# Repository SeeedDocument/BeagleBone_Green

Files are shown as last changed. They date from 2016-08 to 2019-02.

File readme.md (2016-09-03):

BeagleBone Green
---

**SKU**: [102010027](http://www.seeedstudio.com/SeeedStudio-BeagleBone-Green-p-2504.html)

**Wiki Link**: [wiki.seeed.cc](wiki.seeed.cc)

###Change Log:

- **2016-8-29:** update and create repos by loovee (loovee@seeed.cc)

--------
This document is written by Seeed Studio and is licensed under MIT License.

Contributing to this document is warmly welcomed. You can do this basically by
[forking](https://help.github.com/articles/fork-a-repo), committing modifications and then [pulling requests](https://help.github.com/articles/using-pull-requests) (follow the links above
for operating guide). Adding change log and your contact into file header is encouraged.
Thanks for your contribution.

Seeed is a hardware innovation platform for makers to grow inspirations into differentiating products. By working closely with technology providers of all scale, Seeed provides accessible technologies with quality, speed and supply chain knowledge. When prototypes are ready to iterate, Seeed helps productize 1 to 1,000 pcs using in-house engineering, supply chain management and agile manufacture forces. Seeed also team up with incubators, Chinese tech ecosystem, investors and distribution channels to portal Maker startups beyond.

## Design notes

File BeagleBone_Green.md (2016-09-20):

---
title: BeagleBone Green
category: BeagleBone, IoT
bzurl: https://www.seeedstudio.com/SeeedStudio-BeagleBone-Green-p-2504.html
oldwikiname: BeagleBone_Green
prodimagename: cover.jpg
surveyurl: https://www.research.net/r/seeed_bbg
sku: 102010027
---

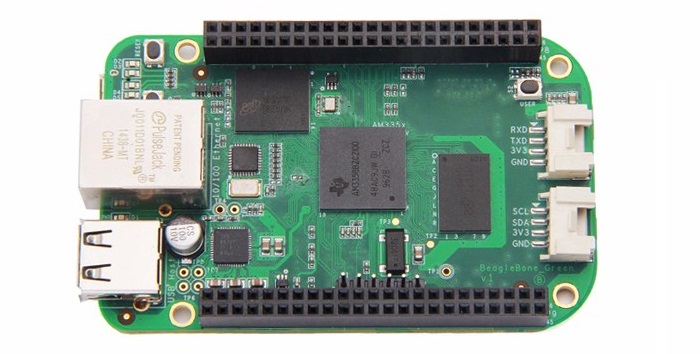
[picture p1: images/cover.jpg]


SeeedStudio BeagleBone Green (BBG) is a low cost, open-source, community supported development platform for developers and hobbyists. It is a joint effort by [BeagleBoard.org](http://beagleboard.org/) and Seeed Studio. It is based on the classical open-source hardware design of [BeagleBone Black](http://beagleboard.org/black) and developed into this differentiated version. The BBG includes two Grove connectors, making it easier to connect to the large family of Grove sensors. The on-board HDMI is removed to make room for these Grove connectors.

Boot Linux in under 10 seconds and get started on development in less than 5 minutes with just a single USB cable.

(http://www.seeedstudio.com/SeeedStudio-BeagleBone-Green-p-2504.html)

##Features
------

* **Fully Compatible with BeagleBone Black**
* **Processor: AM335x 1GHz ARMR Cortex-A8**
    * 512MB DDR3 RAM
    * 4GB 8-bit eMMC on-board flash storage
    * 3D graphics accelerator
    * NEON floating-point accelerator
    * 2x PRU 32-bit microcontrollers
* **Connectivity**
    * USB client for power & communications
    * USB host
    * Ethernet
    * 2x 46 pin headers
    * 2x Grove connectors (I2C and UART)
* **Software Compatibility**
    * Debian
    * Android
    * Ubuntu
    * Cloud9 IDE on Node.js w/ BoneScript library
    * plus much more

##Specification
------

|Item|Value|
|----|---|
|Processor|	AM335x 1GHz ARMR Cortex-A8|
|RAM|	512MB DDR3|
|on-board Flash Storage	|4GB eMMC|
|CPU Supports	|NEON floating-point & 3D graphics accelerator|
|Micro USB	Supports |powering & communications|
|USB |Host	1|
|Grove Connectors	|2 (One I2C and One UART) |
|GPIO	|2 x 46 pin headers|
|Ethernet	|1|
|Operating Temperature	|0 ~ 75 |

##Application Ideas

* Internet of Things
* Smart House
* Industrial
* Automation & Process Control
* Human Machine Interface
* Sensor Hub
* Robot

Here are some funny projects for your reference.

|Home Center|Retro Lamp|Drive a Motor|
|---|-----|---|
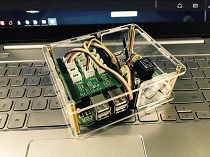
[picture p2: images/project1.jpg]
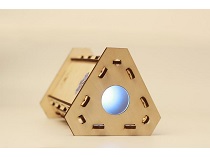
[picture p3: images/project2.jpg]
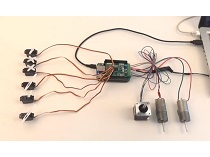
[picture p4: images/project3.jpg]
||||
|[MAKE IT NOW!](http://www.instructables.com/id/Home-Control-Center-Using-BeagleBone-Green-Wireles/)|[MAKE IT NOW!](http://www.instructables.com/id/DIY-a-Retro-Wooden-Lamp-with-BBG/)|[MAKE IT NOW!](http://www.instructables.com/id/A-BeagleBone-Tutorial-Getting-Started-With-Motor-B/)|

|BBG Acrylic Case|GPIO Control|Smart Light|
|---|-----|---|
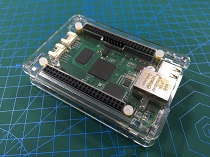
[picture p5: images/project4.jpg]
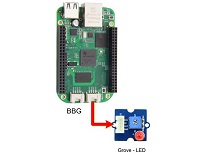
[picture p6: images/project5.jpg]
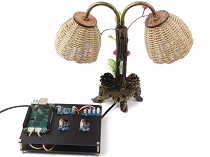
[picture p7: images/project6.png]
||||
|[MAKE IT NOW!](http://www.instructables.com/id/5-Design-of-Laser-Cut-Cases-for-5-Popular-Platform/)|[MAKE IT NOW!](http://www.seeed.cc/How-to-use-the-Grove-UART-port-as-a-GPIO-on-BBG-p-365.html)|[MAKE IT NOW!](http://www.seeed.cc/Smart-Light-Demo-with-BBG-%26amp%3B-BBG-Start-Kit(HA)-p-366.html)|

##Hardware Overview

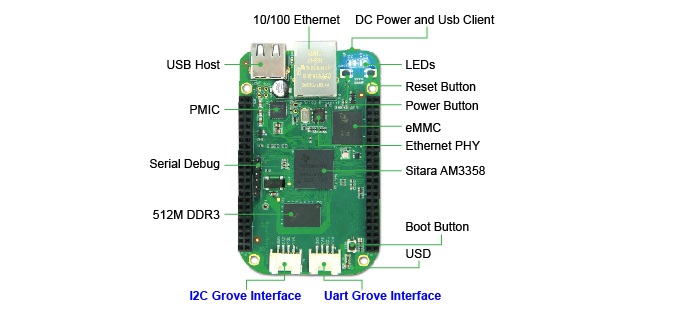
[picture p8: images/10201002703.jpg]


* **USB Host** - USB Host
* **DC Power and USB Client** - Power the board and act as client
* **LEDs**
    * **D2** is configured at boot to blink in a heartbeat pattern
    * **D3** is configured at boot to light during microSD card accesses
    * **D4** is configured at boot to light during CPU activity
    * **D5** is configured at boot to light during eMMC accesses
* **Boot button**
    * When there's a SD card insert, the system will boot from SD card first, if you want to boot from eMMC, press this button and then power on. 
    * Use as a normal button after boot, connect to **GPIO_72**
* **I2C Grove Interface** - Connected to **I2C2**
* **Uart Grove Interface** - Connected to **UART2**
* **Serial Debug** - Connect to **UART0**, PIN1~PIN6: GND, NC, NC, RX, TX, NC, note that pin1 is near to the USB.

###Pin map

Each digital I/O pin has 8 different modes that can be selected, including GPIO.

####65 Possible Digital I/Os

!!!Note
    In GPIO mode, each digital I/O can produce interrupts.

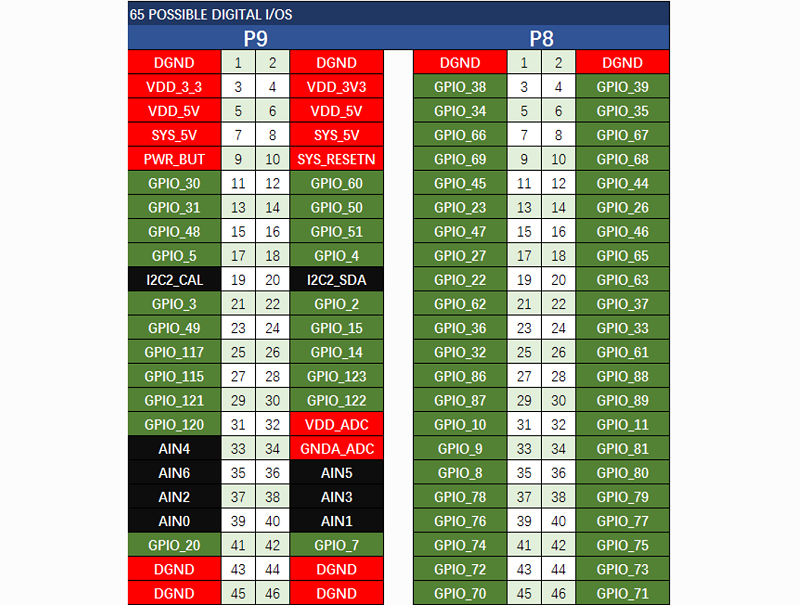
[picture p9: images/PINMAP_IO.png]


####PWMs and Timers

!!!Note
    Up to 8 digital I/O pins can be configured with pulse-width modulators (PWM) to produce signals to control motors or create pseudo analog voltage levels, without taking up any extra CPU cycles.

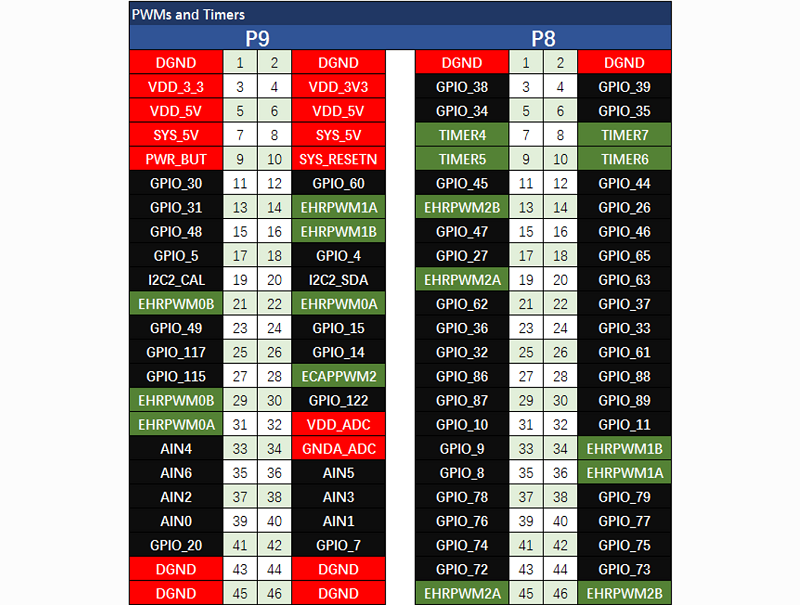
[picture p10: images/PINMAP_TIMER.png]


####Analog Inputs

!!!Note
    Make sure you don't input more than 1.8V to the analog input pins. This is a single 12-bit analog-to-digital converter with 8 channels, 7 of which are made available on the headers.

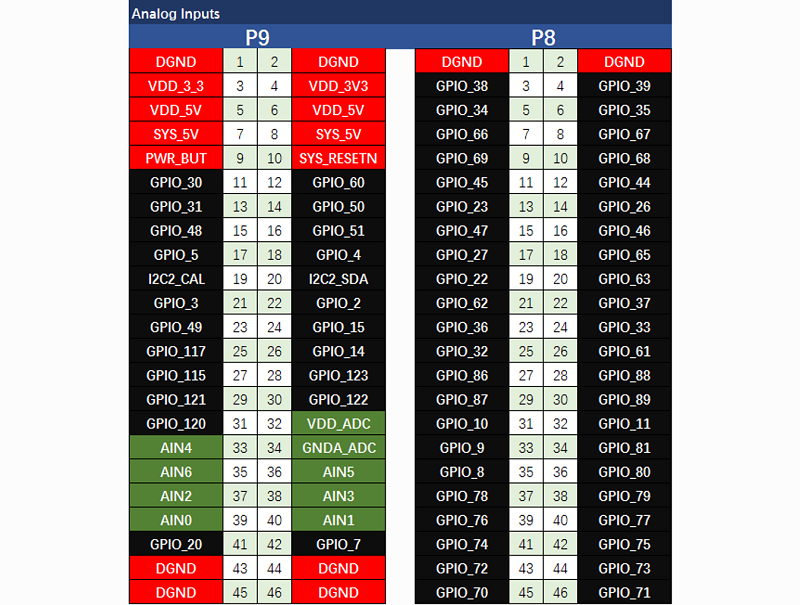
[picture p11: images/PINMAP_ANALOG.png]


####UART

!!!Note
    There is a dedicated header for getting to the UART0 pins and connecting a debug cable. Five additional serial ports are brought to the expansion headers, but one of them only has a single direction brought to the headers.

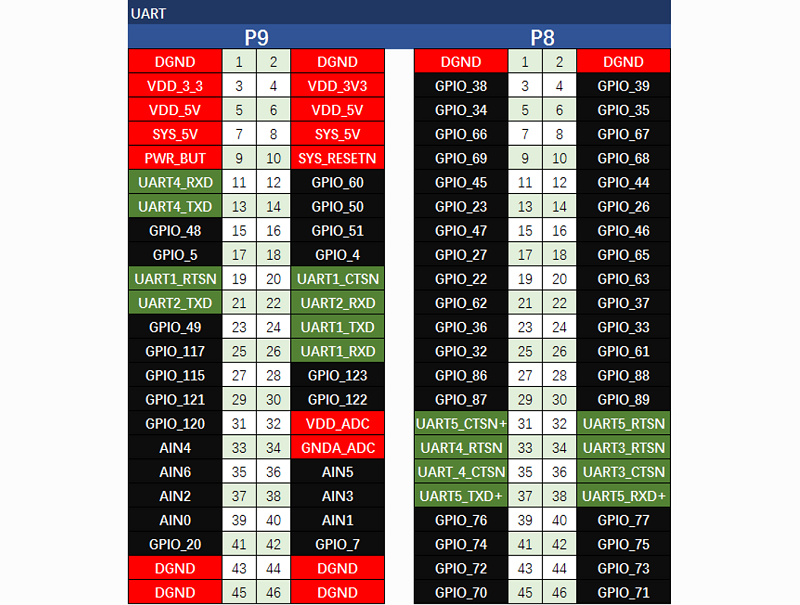
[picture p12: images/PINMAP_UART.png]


####I2C

!!!Note
    The first I2C bus is utilized for reading EEPROMS on cape add-on boards and can't be used for other digital I/O operations without interfering with that function, but you can still use it to add other I2C devices at available addresses. The second I2C bus is available for you to configure and use.

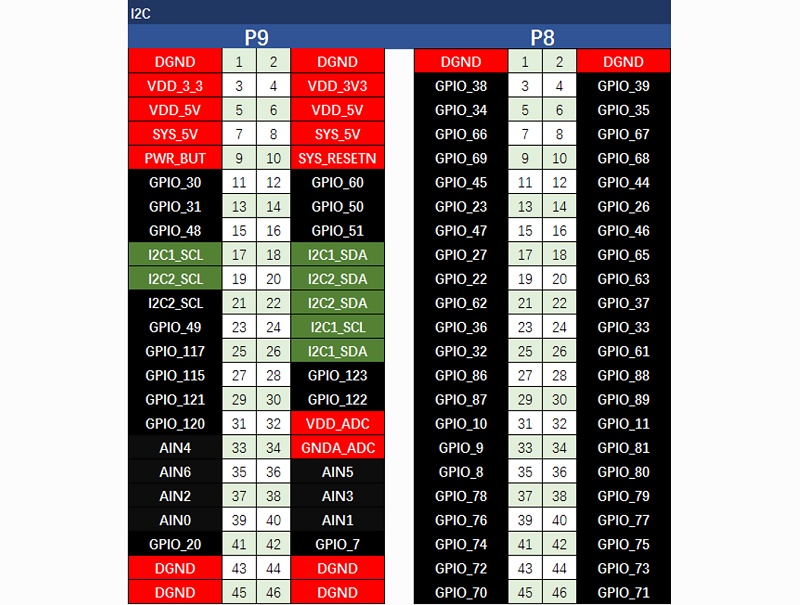
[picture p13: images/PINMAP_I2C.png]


####SPI

!!!Note
    For shifting out data fast, you might consider using one of the SPI ports.

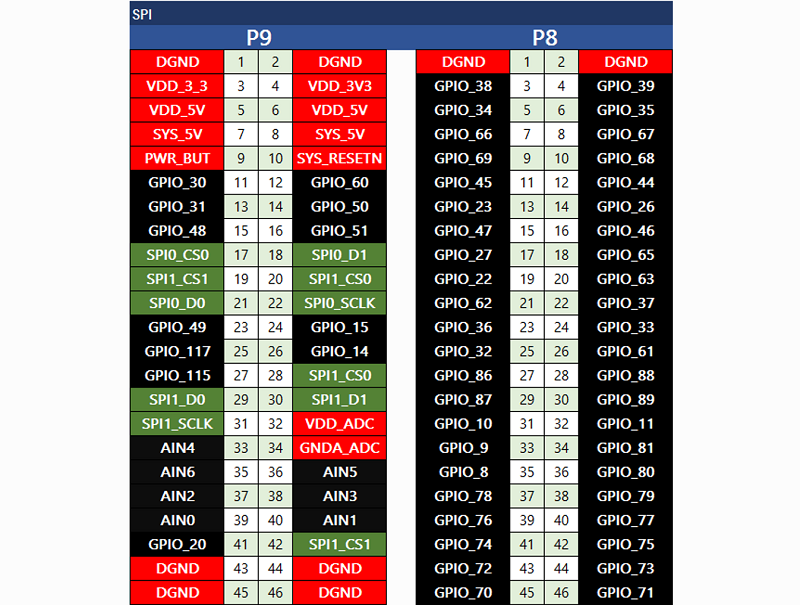
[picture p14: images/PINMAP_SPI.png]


##Getting Started
------

!!!Note
    This chapter is writing under Win10. The steps are familiar for the other operate systems.

###STEP1. Plug in your BBG via USB

Use the provided micro USB cable to plug your BBG into your computer. This will both power the board and provide a development interface. BBG will boot Linux from the on-board 2GB or 4GB eMMC. 

BBG will operate as a flash drive providing you with a local copy of the documentation and drivers. Note that this interface may not be used to re-configure the microSD card with a new image, but may be used to update the boot parameters using the uEnv.txt file.

You'll see the PWR LED lit steadily. Within 10 seconds, you should see the other LEDs blinking in their default configurations.

* D2 is configured at boot to blink in a heartbeat pattern
* D3 is configured at boot to light during microSD card accesses
* D4 is configured at boot to light during CPU activity
* D5 is configured at boot to light during eMMC accesses

###STEP2. Install Drivers

Install the drivers for your operating system to give you network-over-USB access to your Beagle. Additional drivers give you serial access to your board.

|Operating System |	USB Drivers |	Comments |
|---|---|---|
|Windows (64-bit) |	[64-bit installer](http://beagleboard.org/static/Drivers/Windows/BONE_D64.exe)	 | |
|Windows (32-bit) |	[32-bit installer](http://beagleboard.org/static/Drivers/Windows/BONE_DRV.exe)||
|Mac OS X|[Network](http://beagleboard.org/static/Drivers/MacOSX/RNDIS/HoRNDIS.pkg) [Serial](http://beagleboard.org/static/Drivers/MacOSX/FTDI/EnergiaFTDIDrivers2.2.18.pkg) | Install both sets of drivers.|
|Linux|[mkudevrule.sh](http://beagleboard.org/static/Drivers/Linux/FTDI/mkudevrule.sh)|Driver installation isn't required, but you might find a few udev rules helpful.|

!!!Note
    For window system, please note that:
    
    * Windows Driver Certification warning may pop up two or three times. Click "Ignore", "Install" or "Run"
    * To check if you're running 32 or 64-bit Windows see [this](https://support.microsoft.com/kb/827218).
    *  On systems without the latest service release, you may get an error (0xc000007b). In that case, please [install](https://www.microsoft.com/en-us/download/confirmation.aspx?id=13523) and retry: 
    * You may need to reboot Windows.
    * These drivers have been tested to work up to Windows 10

!!!Note
    Additional FTDI USB to serial/JTAG information and drivers are available from [https://www.ftdichip.com/Drivers/VCP.htm](https://www.ftdichip.com/Drivers/VCP.htm).

!!!Note
    Additional USB to virtual Ethernet information and drivers are available from [https://www.linux-usb.org/gadget/](https://www.linux-usb.org/gadget/) and [https://joshuawise.com/horndis](https://joshuawise.com/horndis).

###STEP3. Browse to your Beagle

Using either Chrome or Firefox (Internet Explorer will NOT work), browse to the web server running on your board. It will load a presentation showing you the capabilities of the board. Use the arrow keys on your keyboard to navigate the presentation.

Click [http://192.168.7.2](http://192.168.7.2) to launch to your BBG.
Older software images require you to EJECT the BEAGLE_BONE drive to start the network. With the latest software image, that step is no longer required.

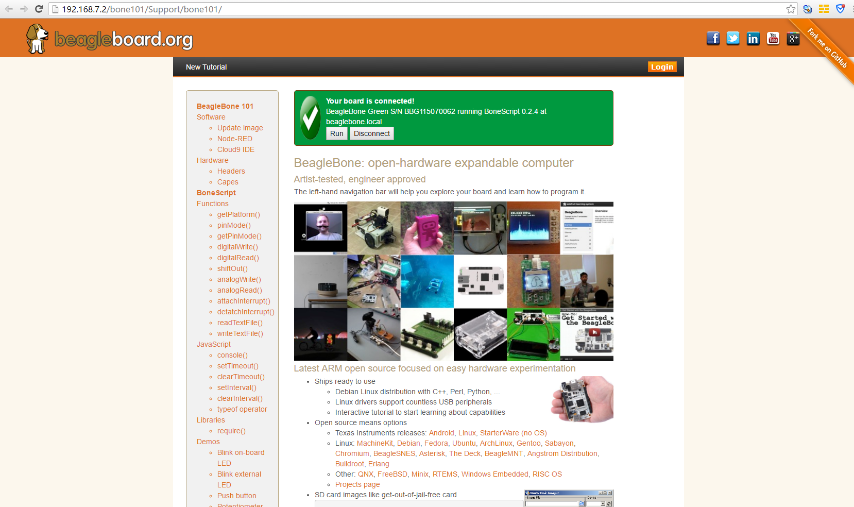
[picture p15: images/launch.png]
Click to view larger image


###STEP4. Cloud9 IDE

To begin editing programs that live on your board, you can use the Cloud9 IDE by click

(http://192.168.7.2:3000/ide.html)

##Update to latest software
-----

You need to update the board to latest software to keep a better performance, here we will show you how to make it step by step. 

###STEP1. Download the latest software image

First of all, you have to download the suitable image here. 

(http://beagleboard.org/latest-images)

!!!Note
    Due to sizing necessities, this download may take about 30 minutes or more. 

The file you download will have an **.img.xz** extension. This is a compressed sector-by-sector image of the SD card. 

###STEP2. Install compression utility and decompress the image

Download and install [7-zip.](http://www.7-zip.org/download.html) 

!!!Note
    Choose a version that suitable for your system.

Use 7-zip to decompress the SD card **.img file**

###STEP3. Install SD card programming utility

Download and install [Image Writer for Windows](https://sourceforge.net/projects/win32diskimager/files/latest/download). Be sure to download the binary distribution.

###STEP4. Write the image to your SD card

You need a SD adapter to connect your microSD card to your computer at the first. Then use the software Image Write for Windows to write the decompressed image to your SD card.

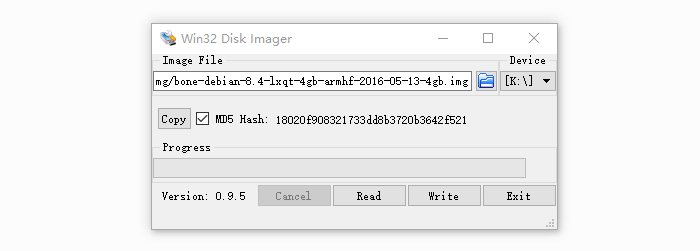
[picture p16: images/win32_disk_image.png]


Click on **Write** button, then the process is started. 

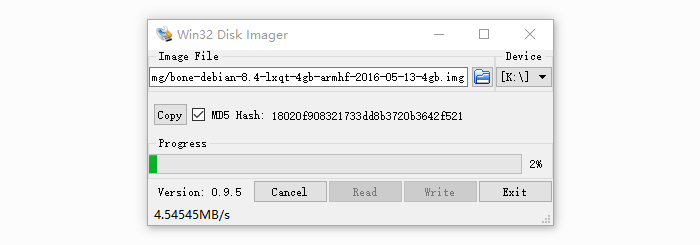
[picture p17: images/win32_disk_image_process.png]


!!!Note
    * You may see a warning about damaging your device. This is fine to accept as long as you are pointing to your SD card for writing.
    * You should not have your BeagleBone connected to your computer at this time.
    * This process may need up to 10 minutes.

###STEP5. Boot your board off of the SD card

Insert SD card into your (powered-down first) board. Then the board will boot from the SD card.

!!!Note
    If you don't need to write the image to your on-board eMMC, you don't need to read the last of this chapter.  Otherwise pleas go ahead.

If you desire to write the image to your on-board eMMC, you need to launch to the board, and modify a file. 

In **/boot/uEnv.txt**:

    ##enable BBB: eMMC Flasher:
    #cmdline=init=/opt/scripts/tools/eMMC/init-eMMC-flasher-v3.sh
Change to:

    ##enable BBB: eMMC Flasher:
    cmdline=init=/opt/scripts/tools/eMMC/init-eMMC-flasher-v3.sh

Then you will find the 4 user led light as below

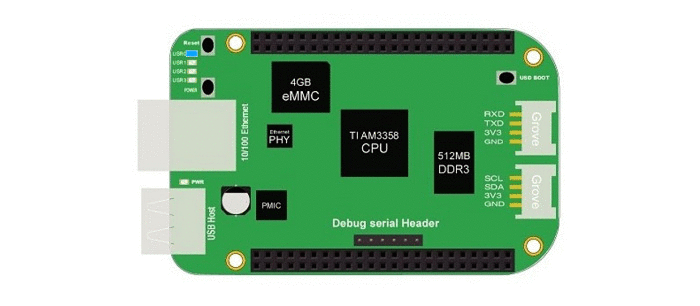
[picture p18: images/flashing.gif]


!!!Note
    If you don't find the upper tracing light, please press the RESET button to reset the board. 
    
When the flashing is complete, all 4 USRx LEDs will be **off**. The latest Debian flasher images automatically power down the board upon completion. This can take up to **10 minutes**. Power-down your board, remove the SD card and apply power again to be complete.

##Grove for BBG
------

Grove is a modular, standardized connecter prototyping system. Grove takes a building block approach to assembling electronics. Compared to the jumper or solder based system, it is easier to connect, experiment and build and simplifies the learning system, but not to the point where it becomes dumbed down.  Some of the other prototype systems out there takes the level down to building blocks.   Good stuff to be learned that way, but the Grove system allows you to build real systems.   It requires some learning and expertise to hook things up.

Below listed the Grove modules that work well with BBG.

|SKU |Name|Interface|link|
|---|-----|-----|---|
|101020054  |Grove - 3-Axis Digital Accelerometer(+16g) |	I2C| [link](http://www.seeedstudio.com/Grove-3-Axis-Digital-Accelerometer%28%C2%B116g%29-p-1156.html)|
|101020071  |Grove - 3-Axis Digital Accelerometer(+400g) |	I2C| [link](http://www.seeedstudio.com/Grove-3-Axis-Digital-Accelerometer%28%C2%B1400g%29-p-1897.html)|
|101020034  |Grove - 3-Axis Digital Compass |	I2C| [link](http://www.seeedstudio.com/Grove-3-Axis-Digital-Compass-p-759.html)|
|101020050  |Grove - 3-Axis Digital Gyro |	Analog| [link](http://www.seeedstudio.com/Grove-3-Axis-Digital-Gyro-p-750.html)|
|101020081	|Grove - 6-Axis Accelerometer&Compass v2.0 |	I2C| [link](http://www.seeedstudio.com/Grove-6-Axis-Accelerometer&Compass-v2.0-p-2476.html)|
|101020072	|Grove - Barometer Sensor(BMP180) |	I2C| [link](http://www.seeedstudio.com/Grove-Barometer-Sensor-%28BMP180%29-p-1840.html)|
|104030010	|Grove - Blue LED |	I/O| [link](http://www.seeedstudio.com/Grove-Blue-LED-p-1139.html)|
|101020003	|Grove - Button	 |I/O| [link](http://www.seeedstudio.com/Grove-Button-p-766.html)|
|111020000	|Grove - Button(P)	 |I/O| [link](http://www.seeedstudio.com/Grove-Button%28P%29-p-1243.html)|
|107020000	|Grove - Buzzer	 |I/O| [link](http://www.seeedstudio.com/Grove-Buzzer-p-768.html)|
|104030006	|Grove - Chainable RGB LED	 |I2C| [link](http://www.seeedstudio.com/Grove-Chainable-RGB-LED-p-850.html)|
|101020030	|Grove - Digital Light Sensor	 |I2C| [link](http://www.seeedstudio.com/Grove-Digital-Light-Sensor-p-1281.html)|
|103020024	|Grove - Finger-clip Heart Rate Sensor	 |I2C| [link](http://www.seeedstudio.com/Grove-Finger-clip-Heart-Rate-Sensor-p-2425.html)|
|101020082	|Grove - Finger-clip Heart Rate Sensor with shell	|I2C|[link](http://www.seeedstudio.com/Grove-Finger-clip-Heart-Rate-Sensor-with-shell-p-2420.html)|
|113020003	|Grove - GPS	 |UART| [link](http://www.seeedstudio.com/Grove-GPS-p-959.html)|
|104030007	|Grove - Green LED	|I/O| [link](http://www.seeedstudio.com/Grove-Green-LED-p-1144.html)|
|103020013	|Grove - I2C ADC	|I2C| [link](http://www.seeedstudio.com/Grove-Green-LED-p-1144.html)|
|103020006	|Grove - I2C Hub	|I2C| [link](http://www.seeedstudio.com/Grove-I2C-Hub-p-851.html)|
|101020079	|Grove - IMU 10DOF	|I2C| [link](http://www.seeedstudio.com/Grove-IMU-10DOF-p-2386.html)|
|101020080	|Grove - IMU 9DOF v2.0	|I2C| [link](http://www.seeedstudio.com/Grove-IMU-9DOF-v2.0-p-2400.html)|
|101020040	|Grove - IR Distance Interrupter	|I/O| [link](http://www.seeedstudio.com/Grove-IR-Distance-Interrupter-p-1278.html)|
|104030011	|Grove - OLED Display 0.96''	|I2C| [link](http://www.seeedstudio.com/Grove-OLED-Display-1.12%22-p-824.html)|
|104030008	|Grove - OLED Display 1.12''	|I2C| [link](http://www.seeedstudio.com/Grove-OLED-Display-0.96%22-p-781.html)|
|104030005	|Grove - Red LED	|I/O| [link](http://www.seeedstudio.com/Grove-Red-LED-p-1142.html)|
|103020005	|Grove - Relay	|I/O| [link](http://www.seeedstudio.com/Grove-Relay-p-769.html)|
|316010005	|Grove - Servo	|I/O| [link](http://www.seeedstudio.com/Grove-Servo-p-1241.html)|
|101020023	|Grove - Sound Sensor	|Analog| [link](http://www.seeedstudio.com/Grove-Sound-Sensor-p-752.html)|
|101020004	|Grove - Switch(P)	|I/O| [link](http://www.seeedstudio.com/Grove-Switch%28P%29-p-1252.html)|
|101020015	|Grove - Temperature Sensor	|Analog| [link](http://www.seeedstudio.com/Grove-Temperature-Sensor-p-774.html)|
|101020019	|Grove - Temperature&Humidity Sensor Pro	|Analog| [link](http://www.seeedstudio.com/Grove-Temperature&Humidity-Sensor-Pro-p-838.html)|

##Cape for BBG
-------

You will need some expansion board when you start a project. There're many cape for BBG already, they include LCD display, motor driver as well as HDMI expansion etc. Below is some of them recommend.

|Grove Cape| Motor Bridge Cape|HDMI Cape|
|---|---|---|
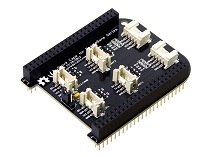
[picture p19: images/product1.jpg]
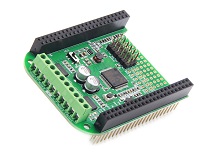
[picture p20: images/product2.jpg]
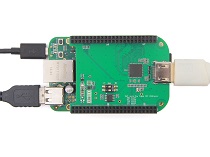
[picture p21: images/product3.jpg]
||||
|[GET ONE NOW!](http://www.seeedstudio.com/Grove-Cape-for-BeagleBone-Series-p-1718.html)|[GET ONE NOW!](http://www.seeedstudio.com/Motor-Bridge-Cape-p-2569.html)|[GET ONE NOW!](http://www.seeedstudio.com/SeeedStudio-BeagleBone-Green-HDMI-Cape-p-2570.html)|

|Grove Cape| 5 Inch LCD|7 Inch LCD|
|---|---|---|
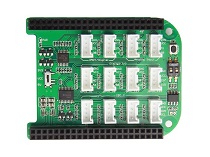
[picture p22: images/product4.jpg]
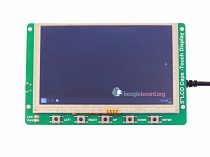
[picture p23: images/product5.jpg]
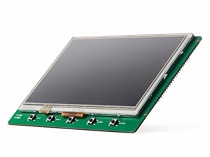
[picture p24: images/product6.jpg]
||||
|[GET ONE NOW!](http://www.seeedstudio.com/Grove-Base-Cape-for-Beaglebone-v2.0-p-2644.html)|[GET ONE NOW!](http://www.seeedstudio.com/5-Inch-BeagleBone-Green-LCD-Cape-with-Resistive-Touch-p-2642.html)|[GET ONE NOW!](http://www.seeedstudio.com/7-Inch-BeagleBone-Green-LCD-Cape-with-Resistive-Touch-p-2643.html)|

##References and Resources

###References
There're many references to help you to get more information about the board. 

* [BeagleBoard Main Page](http://beagleboard.org/)
* [BeagleBone Green info at BeagleBoard page](http://beagleboard.org/green)
* [BeagleBoard Getting Started](http://beagleboard.org/getting-started)
* [Troubleshooting](http://beagleboard.org/getting-started#troubleshooting)
* [Hardware documentation](http://beagleboard.org/getting-started#hardware)
* [Projects of BeagleBoard](http://beagleboard.org/project)

###Resources
-----

* [BEAGLEBONE_GREEN SRM(v1a)(pdf)](https://github.com/SeeedDocument/BeagleBone_Green/raw/master/resources/BBG_SRM_V1a_20151009.pdf)
* [BEAGLEBONE_GREEN Schematic(pdf)](https://github.com/SeeedDocument/BeagleBone_Green/raw/master/resources/BEAGLEBONE_GREEN_V1.pdf)
* [BEAGLEBONE_GREEN Schematic(OrCAD)](https://github.com/SeeedDocument/BeagleBone_Green/raw/master/resources/BEAGLEBONE_GREEN_V1_166%28sch%29.rar)
* [BEAGLEBONE_GREEN PCB(OrCAD)](https://github.com/SeeedDocument/BeagleBone_Green/blob/master/resources/BeagleBone_Green_v1.166%28board%29.rar)

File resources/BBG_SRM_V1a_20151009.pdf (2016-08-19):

REF: BBONEGRN_SRM | BeagleBone Green
System Reference Manual | Rev V1a


# BeagleBone Green System Reference Manual

Revision v1
Oct 9, 2015
Reference to the BBB_SRM

System Reference Manual | Rev V1a

THIS DOCUMENT

This work is licensed under the Creative Commons Attribution-Share Alike 3.0 Unported License. To view a copy of this license, visit http://creativecommons.org/licenses/by-sa/3.0/ or send a letter to Creative Commons, 171 Second Street, Suite 300, San Francisco, California, 94105, USA.

All derivative works are to be attributed to Gerald Coley of BeagleBoard.org.

For more information, see http://creativecommons.org/license/results-one?license_code=by-sa

This document is derived from work by Gerald Coley (gerald@beagleboard.org), for hardware questions, please send your email to XiangNan Qu (xiangnan.qu@seeed.cc), for software and ecosystem questions, please direct to Jason Kridner (jkridner@beagleboard.org) and http://beagleboard.org/discuss.

Send all comments and errors concerning this document to the author at xiangnan.qu@seeed.cc

All information in this document is subject to change without notice.

For an up to date version of this document refer to:

http://www.seeedstudio.com/wiki/beaglebone_green

System Reference Manual | Rev V1a

BEAGLEBONE DESIGN

These design materials referred to in this document are *NOT SUPPORTED* and DO NOT constitute a reference design. Only “community” support is allowed via resources at BeagleBoard.org/discuss.

THERE IS NO WARRANTY FOR THE DESIGN MATERIALS, TO THE EXTENT PERMITTED BY APPLICABLE LAW. EXCEPT WHEN OTHERWISE STATED IN WRITING THE COPYRIGHT HOLDERS AND/OR OTHER PARTIES PROVIDE THE DESIGN MATERIALS “AS IS” WITHOUT WARRANTY OF ANY KIND, EITHER EXPRESSED OR IMPLIED, INCLUDING, BUT NOT LIMITED TO, THE IMPLIED WARRANTIES OF MERCHANTABILITY AND FITNESS FOR A PARTICULAR PURPOSE. THE ENTIRE RISK AS TO THE QUALITY AND PERFORMANCE OF THE DESIGN MATERIALS IS WITH YOU. SHOULD THE DESIGN MATERIALS PROVE DEFECTIVE, YOU ASSUME THE COST OF ALL NECESSARY SERVICING, REPAIR OR CORRECTION.

This board was designed as an evaluation and development tool. It was not designed with any other application in mind. As such, the design materials that are provided which include schematic, BOM, and PCB files, may or may not be suitable for any other purposes. If used, the design material becomes your responsibility as to whether or not it meets your specific needs or your specific applications and may require changes to meet your requirements.

System Reference Manual | Rev V1a

## Table of Contents

### 1.0 Introduction6 2.0 Change History 6

### 3.0 Connecting Up Your BeagleBone Green 7

### 4.0 BeagleBone Green Overview 11

5.0 | BeagleBone Green High Level Specification | 15

System Reference Manual | Rev V1a

### 6.0 BeagleBone Green Mechanical 22

### 7.0 Pictures 24 8.0 Support Information 26

## Tables

Table 1.Change History 6
Table 2.BeagleBone Green Features 12

## Figures

Figure 1. | In The Box 7
Figure 2. | Tethered Configuration 8
Figure 3. | USB Connection to the Board 9
Figure 4. | Board Power LED | 10
Figure 5. | Board Boot Status | 10
Figure 6. | Connectors, LEDs and Switches | 13
Figure 7. | Key Components14
Figure 8. | BeagleBone Green Block diagram15
Figure 9. | Board Dimensions | 23
Figure 10. Top Side24
Figure 11. Bottom Side 25

System Reference Manual | Rev V1a

## 1.0 Introduction

This document is the System Reference Manual for the BeagleBone Green and covers its use and design. The board will primarily be referred to in the remainder of this document simply as the board, although it may also be referred to as the BeagleBone Green as a reminder. There are also references to the original BeagleBone as well, and will be referenced as simply BeagleBone.

This design is subject to change without notice as we will work to keep improving the design as the product matures based on feedback and experience. Software updates will be frequent and will be independent of the hardware revisions and as such not result in a change in the revision number.

Make sure you check the support Wiki frequently for the most up to date information. http://www.seeedstudio.com/wiki/beaglebone_green

## 2.0 Change History

This section describes the change history of this document and board. Document changes are not always a result of a board change. A board change will always result in a document change.

### 2.1 Document Change History

Table 1. Change History
REV | Description | Date | By
V1 | Production release | June 3, 2015 | QXN
V1a | Fixed the Features and Specification Table | Oct 9, 2015 | QXN

System Reference Manual | Rev V1a

## 3.0 Connecting Up Your BeagleBone Green

This section provides instructions on how to hook up your board. Two scenarios will be discussed:

1) Tethered to a PC and
2) As a standalone development platform in a desktop PC configuration.

### 3.1 What’s In the Box

In the box you will find three main items as shown in Figure 1.

- BeagleBone Green
- Micro USB to USB Type A Cable
- Instruction card with link to the support WIKI address.

This is sufficient for the tethered scenario and creates an out of box experience where the board can be used immediately with no other equipment needed.


Figure 1. In The Box

System Reference Manual | Rev V1a

### 3.2 Main Connection Scenarios

This section will describe how to connect the board for use. This section is basically a slightly more detailed description of the Quick Start Guide that came in the box. There is also a Quick Start Guide document on the board that should also be referred to. The intent here is that someone looking t purchase the board will be able to read this section and get a good idea as to what the initial set up will be like.

The board can be configured in several different ways, but we will discuss the most common scenarios as described in the Quick Start Guide card that comes in the box.

### 3.3 Tethered To A PC

In this configuration, the board is powered by the PC via the provided USB cable--no other cables are required. The board is accessed either as a USB storage drive or via the browser on the PC. You need to use either Firefox or Chrome on the PC, IEx will not work properly. Figure 2 shows this configuration.


Figure 2. Tethered Configuration

System Reference Manual | Rev V1a

All the power for the board is provided by the PC via the USB cable. In some instances, the PC may not be able to supply sufficient power for the board. In that case, an external 5VDC power supply can be used to power the board through VDD_5V pin in P9 connector, but this should rarely be necessary.

### 3.3.1 Connect the Cable to the Board

1. Connect the small connector on the USB cable to the board as shown in Figure 4. The connector is on the bottom side of the board.


Figure 3. USB Connection to the Board

2. Connect the large connector of the USB cable to your PC or laptop USB port.
3. The board will power on and the power LED will be on as shown in Figure 4 below.


System Reference Manual | Rev V1a

Figure 4. Board Power LED

4. When the board starts to the booting process started by the process of applying power, the LEDs will come on in sequence as shown in Figure 5 below. It will take a few seconds for the status LEDs to come on, so be patient. The LEDs will be flashing in an erratic manner as it begins to boot the Linux kernel.

Figure 5. Board Boot Status

System Reference Manual | Rev V1a

### 3.3.2 Accessing the Board as a Storage Drive

The board will appear around a USB Storage drive on your PC after the kernel has booted, which will take a round 10 seconds. The kernel on the board needs to boot before the port gets enumerated. Once the board appears as a storage drive, do the following:

1) Open the USB Drive folder.
2) Click on the file named start.html
3) The file will be opened by your browser on the PC and you should get a display showing the Quick Start Guide.
4) Your board is now operational! Follow the instructions on your PC screen.

## 4.0 BeagleBone Green Overview

BeagleBone Green (BBG) is based on the classical open-source hardware design of BeagleBone Black (BBB) and added two Grove connectors. It has removed the HDMI port on the BBB and also updated the 5V barrel to Micro USB host.

The main improvement about BeagleBone Green is that adding two Grove connector for supporting Grove system. For more information about Grove system please visit: http://www.seeedstudio.com/wiki/Grove_System

### 4.1 BeagleBone Black Compatibility

The board is intended to be compatible with the BeagleBone Black as much as possible. There are several areas where there are differences between the two designs. These differences are listed below, along with the reasons for the differences.

- Removed the 5VDC Power Jack
- Cost down
- Rarely used
- Normally you can power the board through the Micro USB port
- Removed HDMI framer IC and connector
- Cost down
- If you still need to display with HDMI interface, you can add a HDMI cape
- Replace Mini USB port with Micro USB
- More commonly used
- Grove interface onboard
- There are more than 100 Grove Sensors and Actuators can be easily used
- Focus on the IoT applications

System Reference Manual | Rev V1a

### 4.2 BeagleBone Green Features and Specification

Table 2. BeagleBone Green Features
| Feature
Processor | Sitara AM3358BZCZ100 1GHz, 2000 MIPS
Graphics Engine | SGX530 3D, 20M Polygons/S
SDRAM Memory | 512MB DDR3L 800MHZ
Onboard Flash | 4GB, 8bit Embedded MMC
Power Source | Micro USB Jack,5VDC External Via Expansion Header
PCB | 3.4” x 2.1” , 6 layers
Indicators | 1-Power, 2-Ethernet, 4-User Controllable LEDs
HS USB 2.0 Client Port | Access to USB0, Client mode via Micro USB
HS USB 2.0 Host Port | Access to USB1, Type A Socket, 500mA LS/FS/HS
Serial Port | UART0 access via 6 pin 3.3V TTL Header. Header is populated
Ethernet | 10/100, RJ45
SD/MMC Connector | microSD , 3.3V
Grove Connectors | 1-Uart2, 1-I2C2
User Input | Reset Button Boot Button Power Button
Video Out | Not support
Audio Out | Not support
Expansion Connectors | Power 5V, 3.3V , VDD_ADC(1.8V) 3.3V I/O on all signals McASP0, SPI1, I2C, GPIO(69 max), LCD, GPMC, MMC1, MMC2, 7 AIN(1.8V MAX), 4 Timers, 4 Serial Ports, CAN0, EHRPWM(0,2),XDMA Interrupt, Power button, Expansion Board ID (Up to 4 can be stacked)
Weight | 1.4 oz (39.68 grams)
Power | Refer to Section 6.1.7

System Reference Manual | Rev V1a

### 4.3 Board Component Locations

This section describes the key components on the board. It provides information on their location and function. Familiarize yourself with the various components on the board.

### 4.3.1 Connectors, LEDs, and Switches

Figure 6 below shows the locations of the connectors, LEDs, and switches on the PCB layout of the board.


Figure 6. Connectors, LEDs and Switches

- Power Button alerts the processor to initiate the power down sequence and is used to power down the board.
- 10/100 Ethernet is the connection to the LAN.
- Serial Debug is the serial debug port.
- USB Client is a Micro USB connection to a PC that can also power the board.
- BOOT switch can be used to force a boot from the micro SD card if the power is cycled on the board, removing power and reapplying the power to the board.
- There are four blue LEDS that can be used by the user.
- Reset Button allows the user to reset the processor.
- Micro SD slot is where a micro SD card can be installed.

System Reference Manual | Rev V1a
- Grove Interface is where the Grove sensor is connected to.
- USB Host can be connected different USB interfaces such as Wi-Fi, BT, Keyboard, etc.

4.3.2
Key Components

Figure 7 below shows the locations of the key components on the PCB layout of the board.


Figure 7. Key Components

- Sitara AM3358BZCZ100 is the processor for the board.
- Micron 512MB DDR3L or Kingston 512mB DDR3 is the Dual Data Rate RAM memory.
- TPS65217C PMIC provides the power rails to the various components on the board.
- SMSC Ethernet PHY is the physical interface to the network.
- Micron eMMC is an onboard MMC chip that holds up to 4GB of data.

System Reference Manual | Rev V1a

## 5.0 BeagleBone Green High Level Specification

This section provides the high level specification of the BeagleBone Green.

### 5.1 Block Diagram

Figure 8 below is the high level block diagram of the BeagleBone Green.


Figure 8. BeagleBone Green Block diagram

System Reference Manual | Rev V1a

### 5.2 Processor

Sitara AM3358BZCZ100

### 5.3 Memory

Described in the following sections are the three memory devices found on the board.

5.3.1 512MB DDR3L

A single 256Mb x16 DDR3L 4Gb (512MB) memory device is used. The memory used is is one of two devices:

- MT41K256M16HA-125 from Micron
- D2516EC4BXGGB from Kingston

It will operate at a clock frequency of 400MHz yielding an effective rate of 800MHZ on the DDR3L bus allowing for 1.6GB/S of DDR3L memory bandwidth.

5.3.2 4KB EEPROM

A single 4KB EEPROM is provided on I2C0 that holds the board information. This information includes board name, serial number, and revision information. This is the not the same as the one used on the original BeagleBone. The device was changed for cost reduction reasons. It has a test point to allow the device to be programmed and otherwise to provide write protection when not grounded.

5.3.3 4GB Embedded MMC

A single 4GB embedded MMC (eMMC) device is on the board. The device connects to the MMC1 port of the processor, allowing for 8bit wide access. Default boot mode for the board will be MMC1 with an option to change it to MMC0, the SD card slot, for booting from the SD card as a result of removing and reapplying the power to the board. Simply pressing the reset button will not change the boot mode. MMC0 cannot be used in 8Bit mode because the lower data pins are located on the pins used by the Ethernet port. This does not interfere with SD card operation but it does make it unsuitable for use as an eMMC port if the 8 bit feature is needed.

### 5.3.4 MicroSD Connector

The board is equipped with a single micro SD connector to act as the secondary boot source for the board and, if selected as such, can be the primary boot source. The connector will support larger capacity micro SD cards. The micro SD card is not provided

System Reference Manual | Rev V1a

with the board. Booting from MMC0 will be used to flash the eMMC in the production environment or can be used by the user to update the SW as needed.

### 5.3.5 Boot Modes

As mentioned earlier, there are four boot modes:

- eMMC Boot...This is the default boot mode and will allow for the fastest boot time and will enable the board to boot out of the box using the pre-flashed OS image without having to purchase an microSD card or an microSD card writer.
- SD Boot...This mode will boot from the microSD slot. This mode can be used to override what is on the eMMC device and can be used to program the eMMC when used in the manufacturing process or for field updates.
- Serial Boot...This mode will use the serial port to allow downloading of the software direct. A separate USB to serial cable is required to use this port.
- USB Boot...This mode supports booting over the USB port.

Software to support USB and serial boot modes is not provided by beagleboard.org. Please contact TI for support of this feature.

A switch is provided to allow switching between the modes.

- Holding the boot switch down during a removal and reapplication of power without a microSD card inserted will force the boot source to be the USB port and if nothing is detected on the USB client port, it will go to the serial port for download.
- Without holding the switch, the board will boot try to boot from the eMMC. If it is empty, then it will try booting from the microSD slot, followed by the serial port, and then the USB port.
- If you hold the boot switch down during the removal and reapplication of power to the board, and you have a microSD card inserted with a bootable image, the board will boot from the microSD card.

NOTE: Pressing the RESET button on the board will NOT result in a change of the boot mode. You MUST remove power and reapply power to change the boot mode. The boot pins are sampled during power on reset from the PMIC to the processor. The reset button on the board is a warm reset only and will not force a boot mode change.

### 5.4 Power Management

The TPS65217C power management device is used along with a separate LDO to provide power to the system. The TPS65217C version provides for the proper voltages required for the DDR3L. This is the same device as used on the original BeagleBone with the exception of the power rail configuration settings which will be changed in the internal EEPROM to the TPS65217C to support the new voltages.

System Reference Manual | Rev V1a

DDR3L requires 1.5V instead of 1.8V on the DDR2 as is the case on the original BeagleBone. The 1.8V regulator setting has been changed to 1.5V for the DDR3L. The LDO3 3.3V rail has been changed to 1.8V to support those rails on the processor. LDO4 is still 3.3V for the 3.3V rails on the processor. An external LDOTLV70233 provides the 3.3V rail for the rest of the board.

### 5.5 PC USB Interface

The board has a Micro USB connector that connects the USB0 port to the processor. This is the most commonly used connector.

### 5.6 Serial Debug Port

Serial debug is provided via UART0 on the processor via a single 1x6 pin header. In order to use the interface a USB to TTL adapter will be required. The header is compatible with the one provided by FTDI and can be purchased for about $12 to $20 from various sources. Signals supported are TX and RX. None of the handshake signals are supported.

### 5.7 USB1 Host Port

On the board is a single USB Type A female connector with full LS/FS/HS Host support that connects to USB1 on the processor. The port can provide power on/off control and up to 500mA of current at 5V. Under USB power, the board will not be able to supply the full 500mA, but should be sufficient to supply enough current for a lower power USB device supplying power between 50 to 100mA.

You can use a wireless keyboard/mouse configuration or you can add a HUB for standard keyboard and mouse interfacing.

### 5.8 Power Sources

The board can be powered from three different sources:

- USB port on a PC
- A power supply with a USB connector.
- Expansion connectors

The USB cable is shipped with each board. This port is limited to 500mA by the Power Management IC. It is possible to change the settings in the TPS65217C to increase this current, but only after the initial boot. And, at that point the PC most likely will complain, but you can also use a dual connector USB cable to the PC to get to 1A.

The power supply is not provided with the board but can be easily obtained from

System Reference Manual | Rev V1a

numerous sources. A 1A supply is sufficient to power the board, but if there is a cape plugged into the board or you have a power hungry device or hub plugged into the host port, then more current may needed from the P9 Expansion connector VDD_5V pin.

Power routed to the board via the expansion header could be provided from power derived on a cape.

### 5.9 Reset Button

When pressed and released, causes a reset of the board. The reset button used on the BeagleBone Black is a little larger than the one used on the original BeagleBone. It has also been moved out to the edge of the board so that it is more accessible.

### 5.10 Power Button

A power button is provided near the reset button close to the Ethernet connector. This button takes advantage of the input to the PMIC for power down features. While a lot of capes have a button, it was decided to add this feature to the board to ensure everyone had access to some new features. These features include:

- Interrupt is sent to the processor to facilitate an orderly shutdown to save files and to un-mount drives.
- Provides ability to let processor put board into a sleep mode to save power.
- Can alert processor to wake up from sleep mode and restore state before sleep was entered.

If you hold the button down longer than 8 seconds, the board will power off if you release the button when the power LED turns off. If you continue to hold it, the board will power back up completing a power cycle.

We recommend that you use this method to power down the board. It will also help prevent contamination of the SD card or the eMMC.

If you do not remove the power jack, you can press the button again and the board will power up.

### 5.11 Indicators

There are a total of five blue LEDs on the board.

- One blue power LED indicates that power is applied and the power management IC is up. If this LED flashes when applying power, it means that an excess current flow was detected and the PMIC has shut down.

System Reference Manual | Rev V1a
- Four blue LEDs that can be controlled via the SW by setting GPIO pins.

In addition, there are two LEDs on the RJ45 to provide Ethernet status indication. One is yellow (100M Link up if on) and the other is green (Indicating traffic when flashing).

### 5.12 CTI JTAG Header

A place for an optional 20 pin CTI JTAG header is provided on the board to facilitate the SW development and debugging of the board by using various JTAG emulators. This header is not supplied standard on the board. To use this, a connector will need to be soldered onto the board.

If you need the JTAG connector you can solder it on yourself. No other components are needed. The connector is made by Samtec and the part number is FTR-110-03-G-D-06. You can purchase it from http://www.digikey.com/.

### 5.13 Grove Interfaces

There are two Grove connectors on the board:

- I2C…The J4 connector is I2C interface. It accesses to the processor’s I2C2 interface and also connect with the P9 expansion header’s I2C2 pins. The Grove I2C connector is for the connection of Grove sensors with I2C interface.
- Uart…The J5 connector is UART interface. It accesses to the processor’s UART2 interface and also connect with the P9 expansion header’s UART2 pins. The Grove UART connector is for the connection of Grove sensors with UART interface.

Because of I2C and UART Interface can be setup to GPIO , the Groves with Digital interface are supported for both Connectors.

If you want to connect more Grove modules , see Grove Cape for BeagleBone Series innovated by Seeedstudio:

http://www.seeedstudio.com/depot/Grove-Cape-for-BeagleBone-Series-p-1718.html

For more information about Grove system, please visit: http://www.seeedstudio.com/wiki/Grove_System

### 5.14 Cape Board Support

The BeagleBone Green has the ability to accept up to four expansion boards or capes that can be stacked onto the expansion headers. The word cape comes from the shape of the board as it is fitted around the Ethernet connector on the main board. This notch acts as a key to ensure proper orientation of the cape.

System Reference Manual | Rev V1a

The majority of capes designed for the original BeagleBone or BeagleBone Black will work on the BeagleBone Green. The two main expansion headers will be populated on the board. There are a few exceptions where certain capabilities may not be present or are limited to the BeagleBone Green. These include:

- GPMC bus may NOT be available due to the use of those signals by the eMMC. If the eMMC is used for booting only and the file system is on the microSD card, then these signals could be used.
- Another option is to use the microSD or serial boot modes and not use the eMMC.
- The power expansion header is not on the BeagleBone Green so those functions are not supported.

### 5.15 Expansion Board External Power

A cape can have a jack or terminals to bring in whatever voltages may be needed by that board. Care should be taken not to let this voltage be fed back into any of the expansion header pins.

It is possible to provide 5V to the main board from an expansion board. By supplying a 5V signal into the VDD_5V rail, the main board can be supplied. This voltage must not exceed 5V. You should not supply any voltage into any other pin of the expansion connectors. Based on the board design, this rail is limited to 1A per pin to the BeagleBone Green.

There are several precautions that need to be taken when working with the expansion headers to prevent damage to the board.

1) Do not apply any voltages to any I/O pins when the board is not powered on.
2) Do not drive any external signals into the I/O pins until after the VDD_3V3B rail is up.
3) Do not apply any voltages that are generated from external sources.
4) If voltages are generated from the VDD_5V signal, those supplies must not become active until after the VDD_3V3B rail is up.
5) If you are applying signals from other boards into the expansion headers, make sure you power the board up after you power up the BeagleBone Green or make the connections after power is applied on both boards.

Powering the processor via its I/O pins can cause damage to the processor.

System Reference Manual | Rev V1a

## 6.0 BeagleBone Green Mechanical

### 6.1 Dimensions and Weight

Size: | 3.5” x 2.15” (86.36mm x 53.34mm)
Max height: | .187” (4.76mm)
PCB Layers: | 6 .062”
PCB thickness: | Yes
RoHS Compliant: | 1.4 oz

System Reference Manual | Rev V1a

### 6.2 Board Dimensions


Figure 9. Board Dimensions

System Reference Manual | Rev V1a

## 7.0 Pictures


Figure 10. Top Side

System Reference Manual | Rev V1a


Figure 11. Bottom Side

System Reference Manual | Rev V1a

## 8.0 Support Information

All support for this design is through the BeagleBoard.org community at:

beagleboard@googlegroups.com or
http://beagleboard.org/discuss.

### 8.1 Hardware Design

Design documentation can be found on the eMMC of the board under the documents/hardware directory when connected using the USB cable. Provided there is:

- Schematic in PDF
- Schematic in OrCAD (Cadence Design Entry CIS 16.3)
- PCB Gerber
- PCB Layout File (Allegro)
- Bill of Material
- System Reference Manual (This document).
This directory is not always kept up to date in every SW release due to the frequency of changes of the SW. The best solution is to download the files from the Circuitco WIKI at http://www.seeedstudio.com/wiki/beaglebone_green

### 8.2 Software Updates

It is a good idea to always use the latest software. Instructions for how to update your software to the latest version can be found at: http://www.seeedstudio.com/wiki/beaglebone_green

## 9.0 Document revision

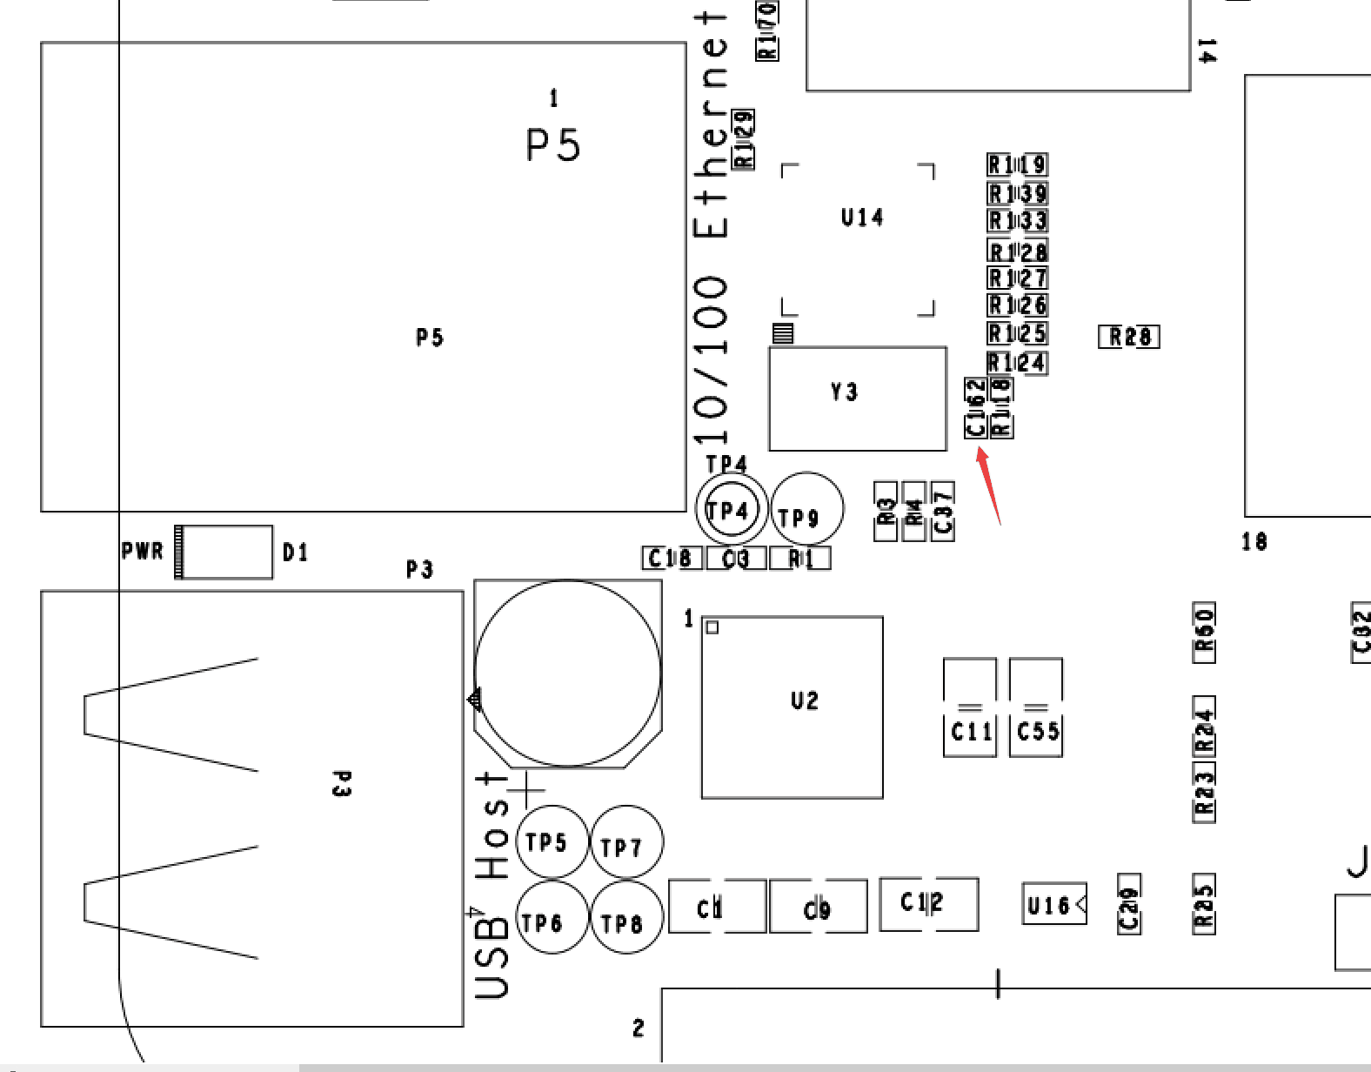
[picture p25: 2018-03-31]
images/Capatictor.png

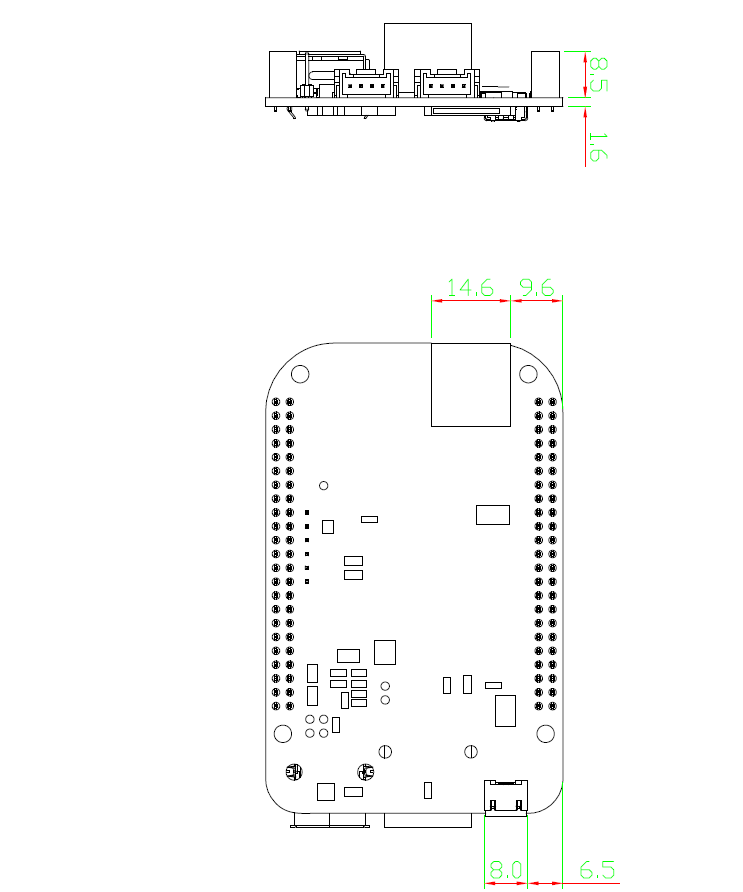
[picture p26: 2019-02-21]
images/BBG_drawing_2.png

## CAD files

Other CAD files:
resources/BBG.skp

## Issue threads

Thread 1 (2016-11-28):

Any Plans to release 3D model?

MrBillium, 2016-11-28:
A 3d model  in stl or step would be  useful in designing cases or cutting panels to fit the BBG's connectors.

There are several out there for the BB Black but I have not found any for the BBG.

Bill

rvega, 2017-02-06:
+1

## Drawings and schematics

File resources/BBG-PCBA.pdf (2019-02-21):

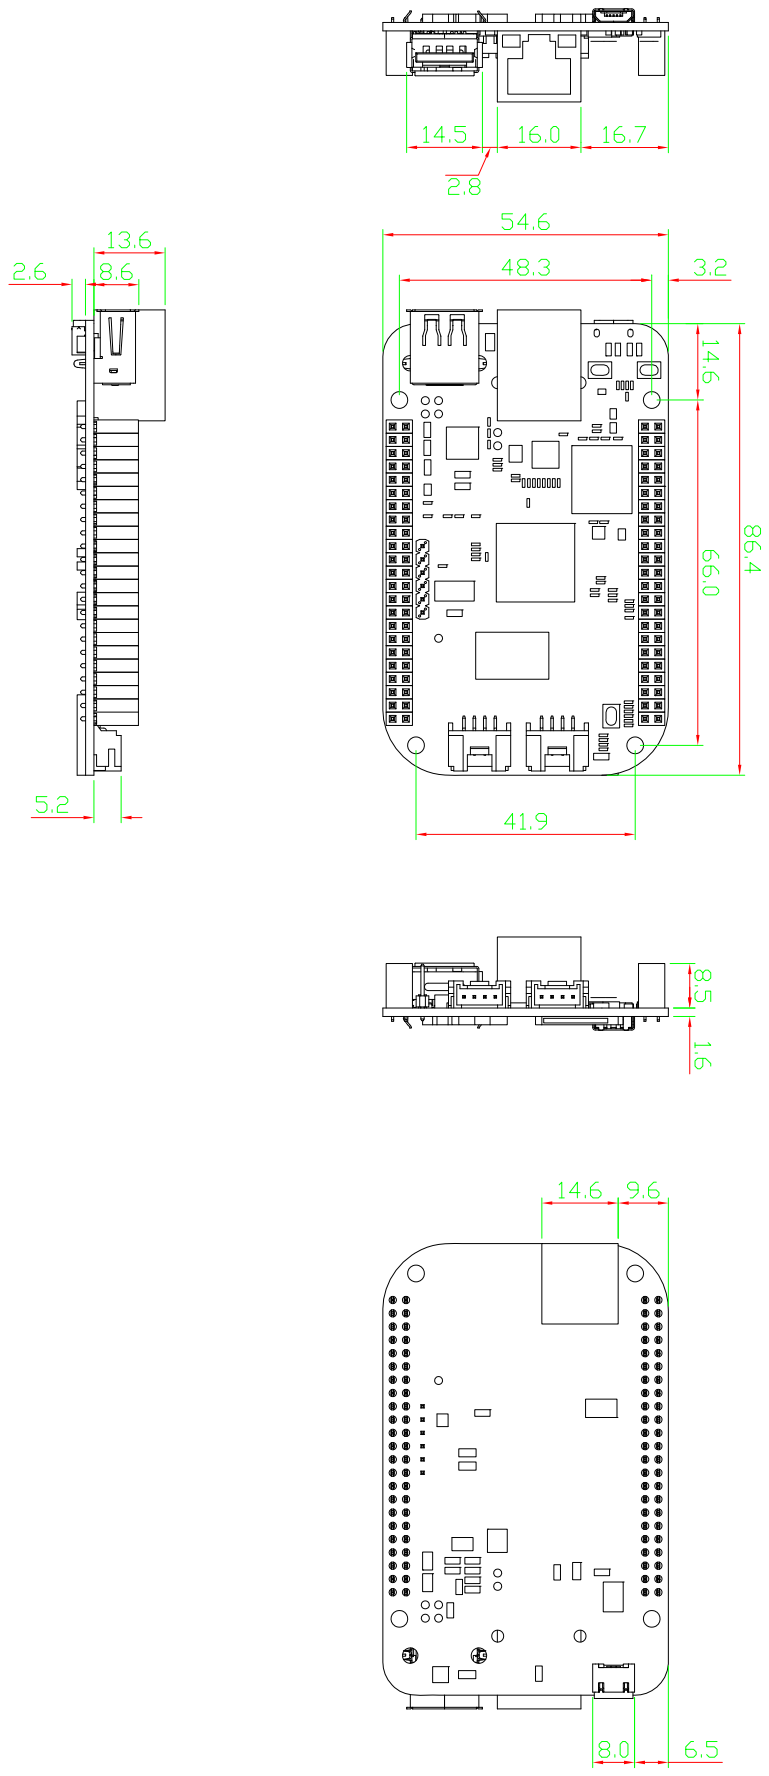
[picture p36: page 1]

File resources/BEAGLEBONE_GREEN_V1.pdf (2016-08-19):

D | D
1

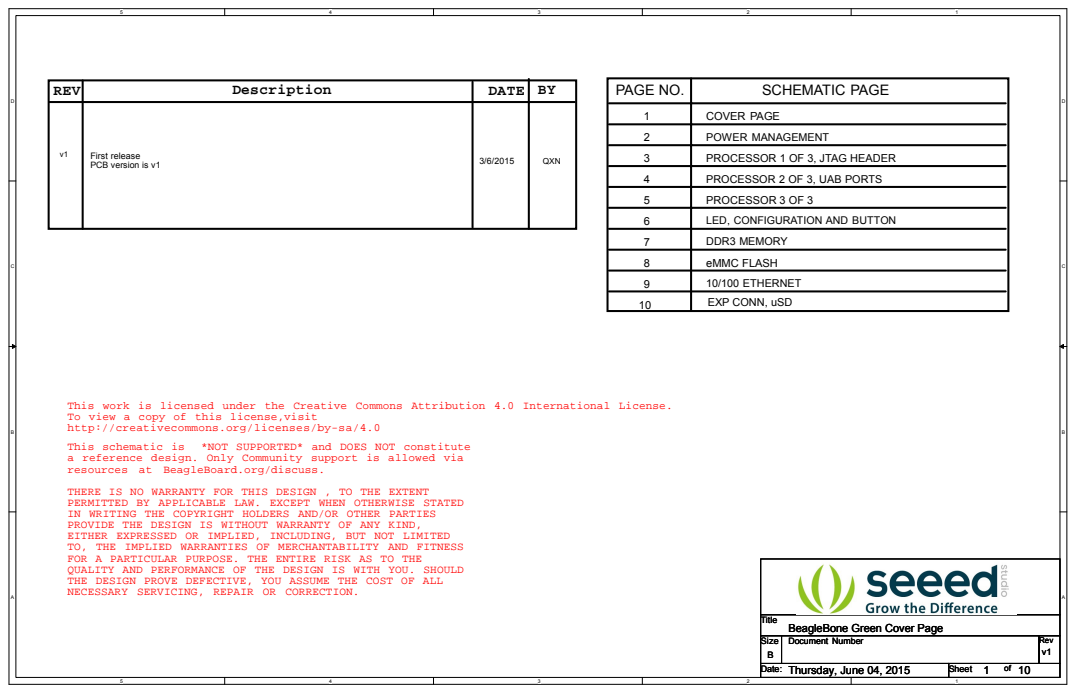
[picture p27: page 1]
PAGE NO.; SCHEMATIC PAGE; This schematic is; *NOT SUPPORTED* and DOES NOT constitute; REV; Description; DATE; QXN

COVER PAGE
POWER MANAGEMENT
PROCESSOR 1 OF 3, JTAG HEADER
PROCESSOR 2 OF 3, UAB PORTS
PROCESSOR 3 OF 3
LED, CONFIGURATION AND BUTTON
DDR3 MEMORY
eMMC FLASH
10/100 ETHERNET
EXP CONN, uSD

First release
PCB version is v1

This work is licensed under the Creative Commons Attribution 4.0 International License.
To view a copy of this license,visit
http://creativecommons.org/licenses/by-sa/4.0
a reference design. Only Community support is allowed via
resources at BeagleBoard.org/discuss.

THERE IS NO WARRANTY FOR THIS DESIGN , TO THE EXTENT
PERMITTED BY APPLICABLE LAW. EXCEPT WHEN OTHERWISE STATED
IN WRITING THE COPYRIGHT HOLDERS AND/OR OTHER PARTIES
PROVIDE THE DESIGN IS WITHOUT WARRANTY OF ANY KIND,
EITHER EXPRESSED OR IMPLIED, INCLUDING, BUT NOT LIMITED
TO, THE IMPLIED WARRANTIES OF MERCHANTABILITY AND FITNESS
FOR A PARTICULAR PURPOSE. THE ENTIRE RISK AS TO THE
QUALITY AND PERFORMANCE OF THE DESIGN IS WITH YOU. SHOULD
THE DESIGN PROVE DEFECTIVE, YOU ASSUME THE COST OF ALL
NECESSARY SERVICING, REPAIR OR CORRECTION.

Title
BeagleBone Green Cover Page

Size Size Size B B B | Document Number Document Number Document Number | Rev Rev Rev v1 v1 v1

Date: Date: Date: Thursday, June 04, 2015 Thursday, June 04, 2015 Thursday, June 04, 2015 | Sheet Sheet Sheet 1 1 1 of of of 10 10 10

D | D

Battery access pins.

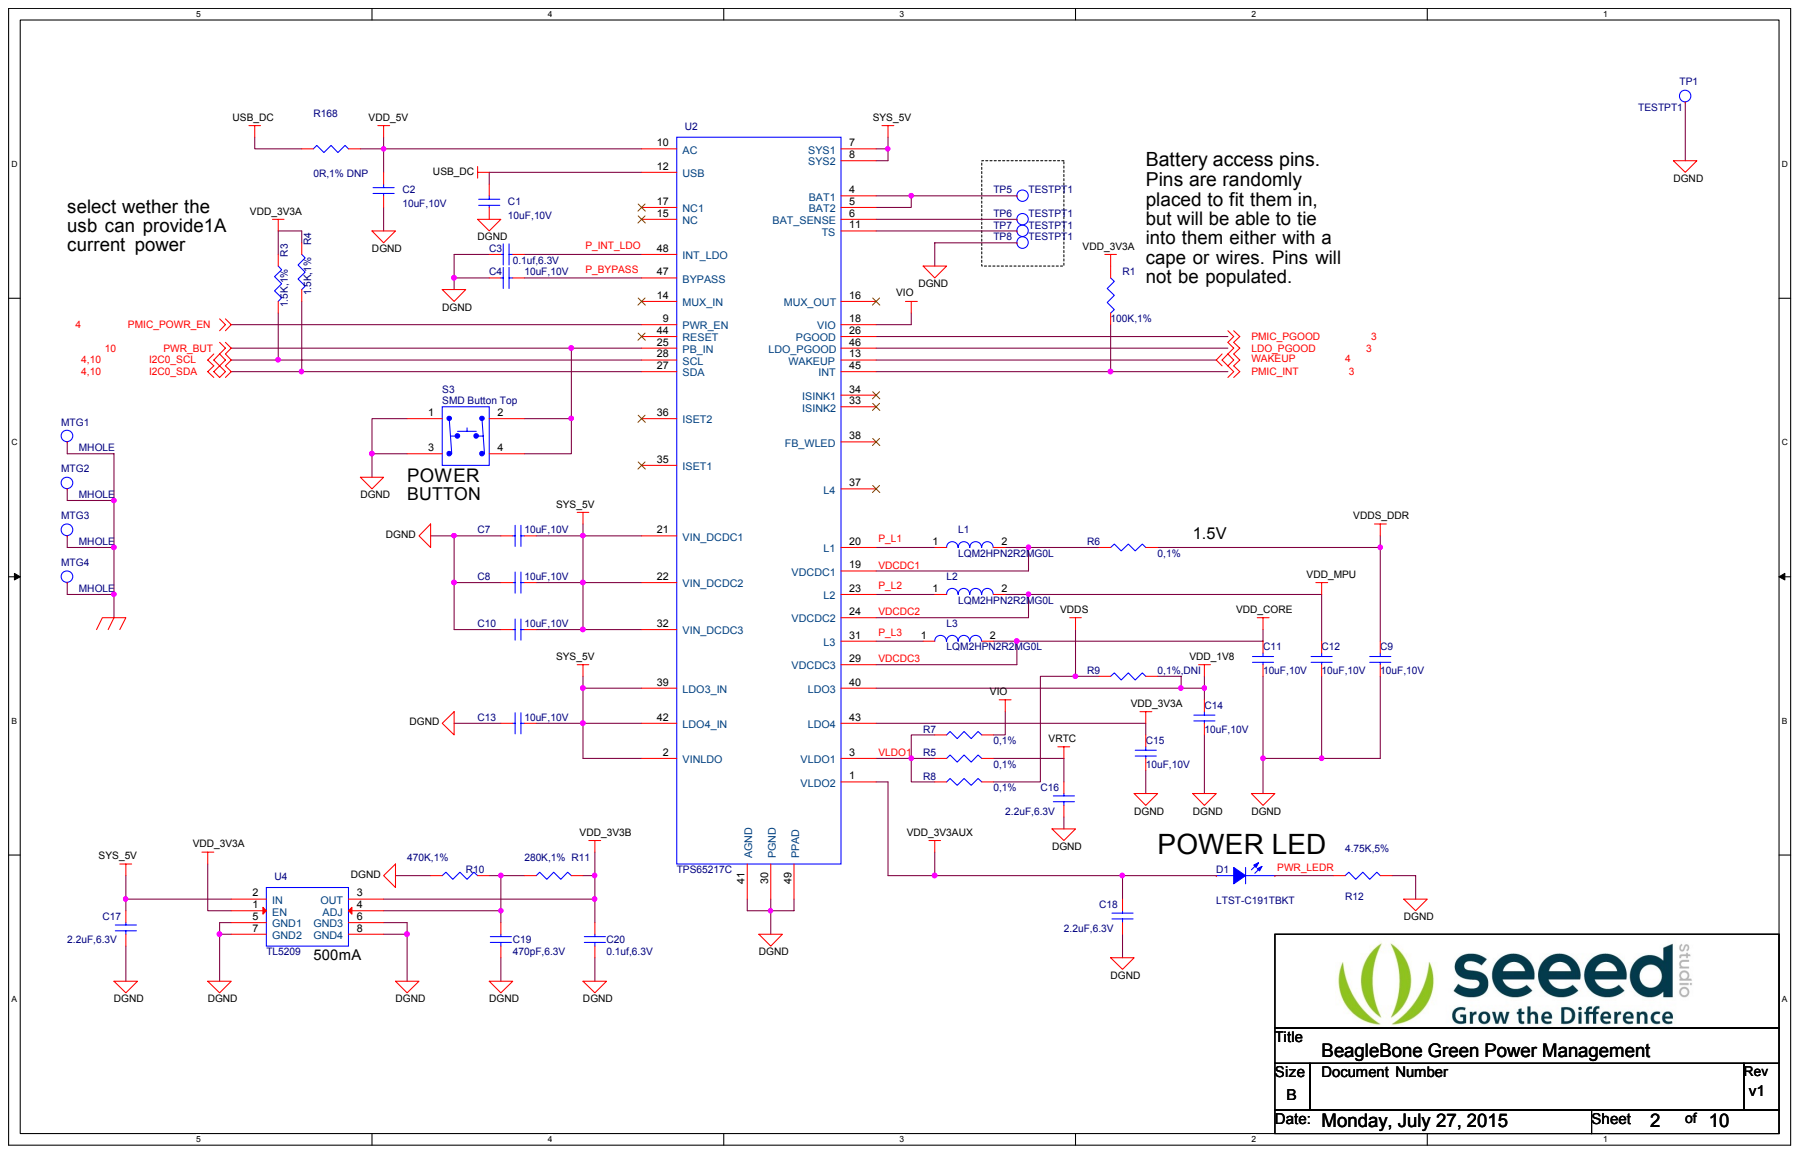
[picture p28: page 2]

Pins are randomly
placed to fit them in,
but will be able to tie
into them either with a
cape or wires. Pins will
not be populated.

Title
BeagleBone Green Power Management

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

Date: Date: Date: Monday, July 27, 2015 Monday, July 27, 2015 Monday, July 27, 2015 | Sheet Sheet Sheet 2 2 2 of of of 10 10 10

# RESET

3.3V

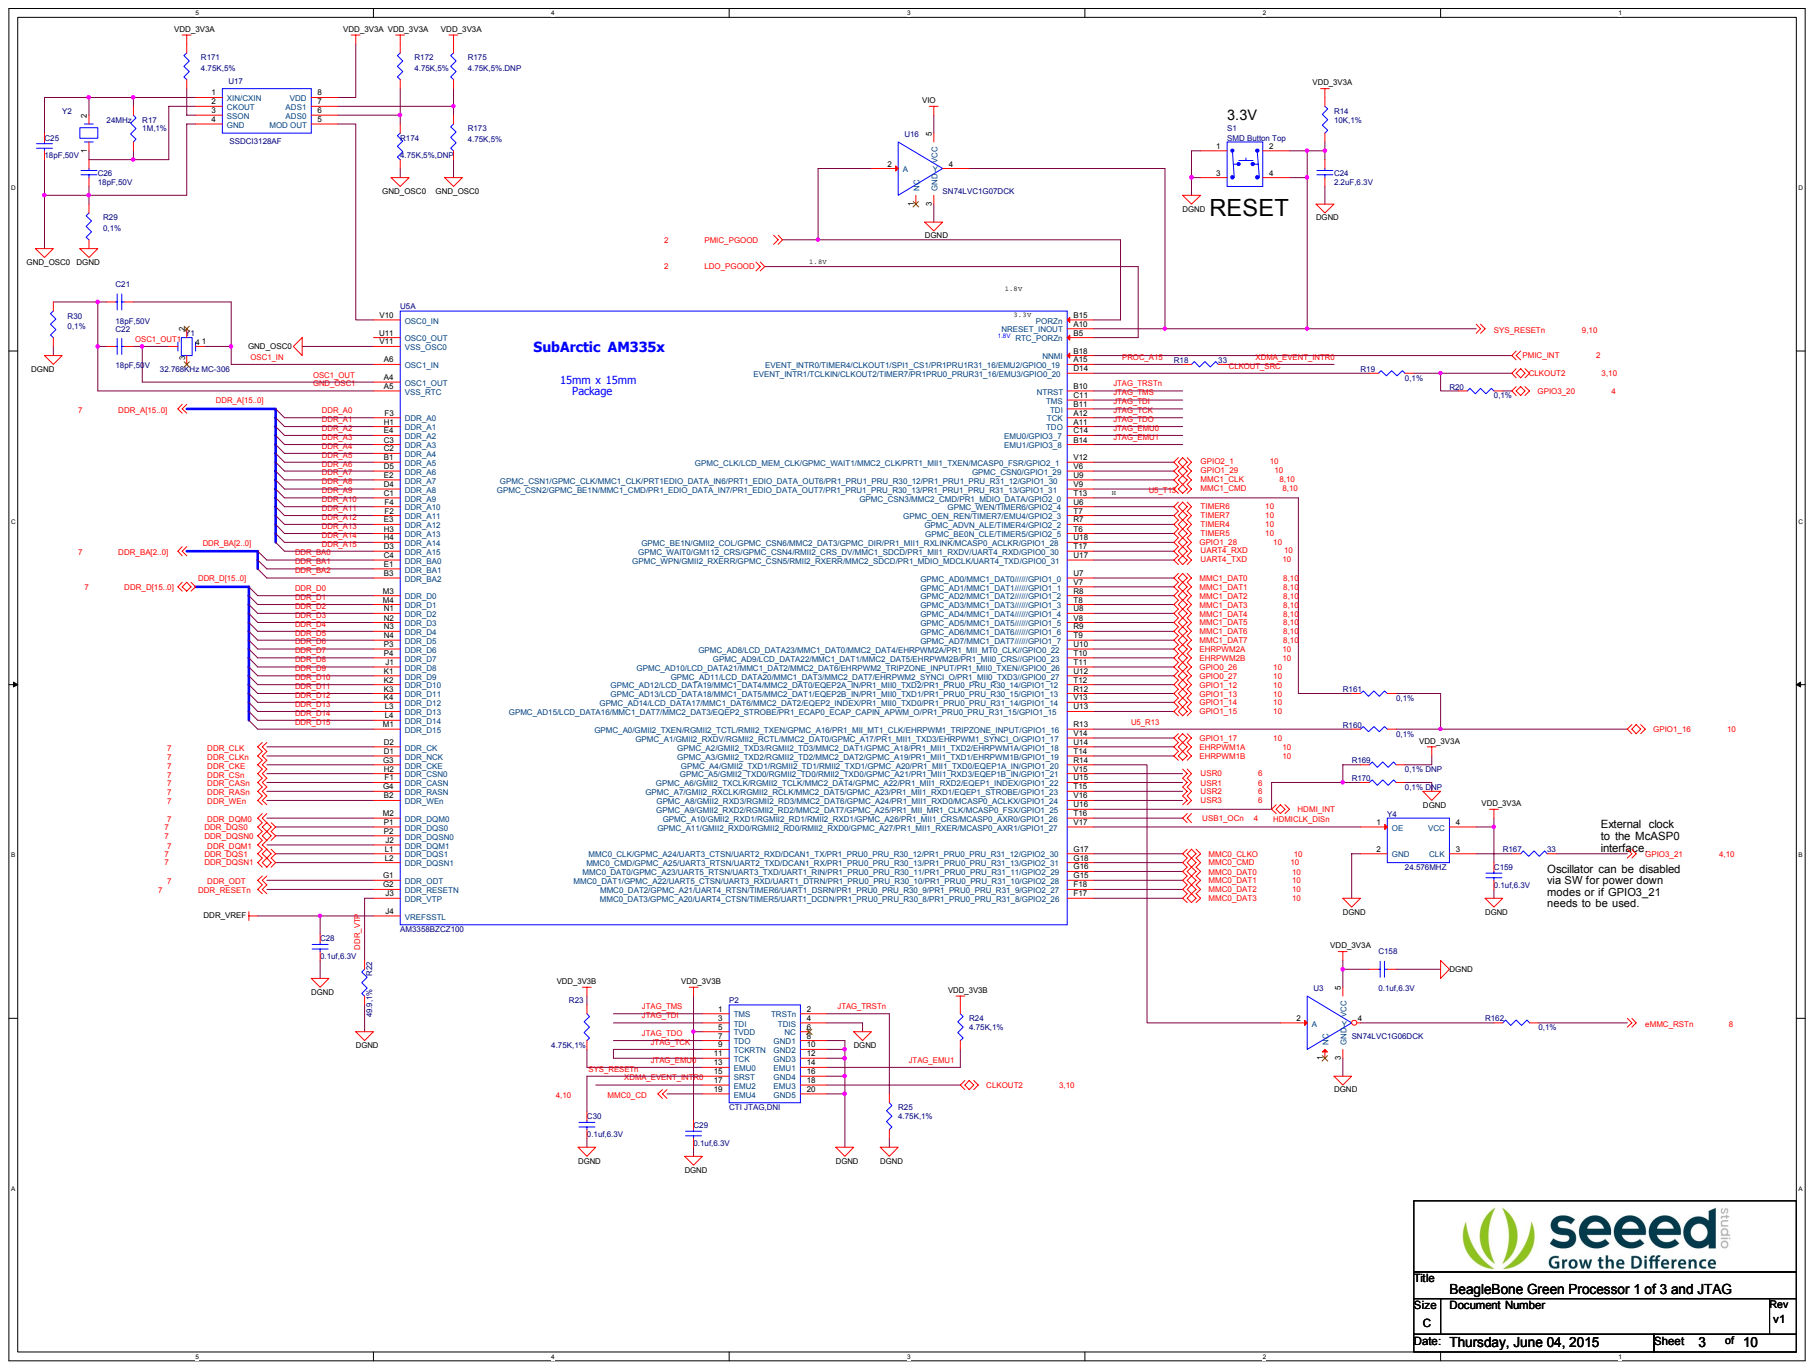
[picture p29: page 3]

VDD_3V3A | VDD_3V3A

Oscillator can be disabled
via SW for power down
modes or if GPIO3_21
needs to be used.

Title
BeagleBone Green Processor 1 of 3 and JTAG

Size Size Size C C C | Document Number Document Number Document Number | Rev Rev Rev v1 v1 v1

Date: Date: Date: Thursday, June 04, 2015 Thursday, June 04, 2015 Thursday, June 04, 2015 | Sheet Sheet Sheet 3 3 3 of of of 10 10 10

# SubArctic AM335X

## 15mm x 15mm

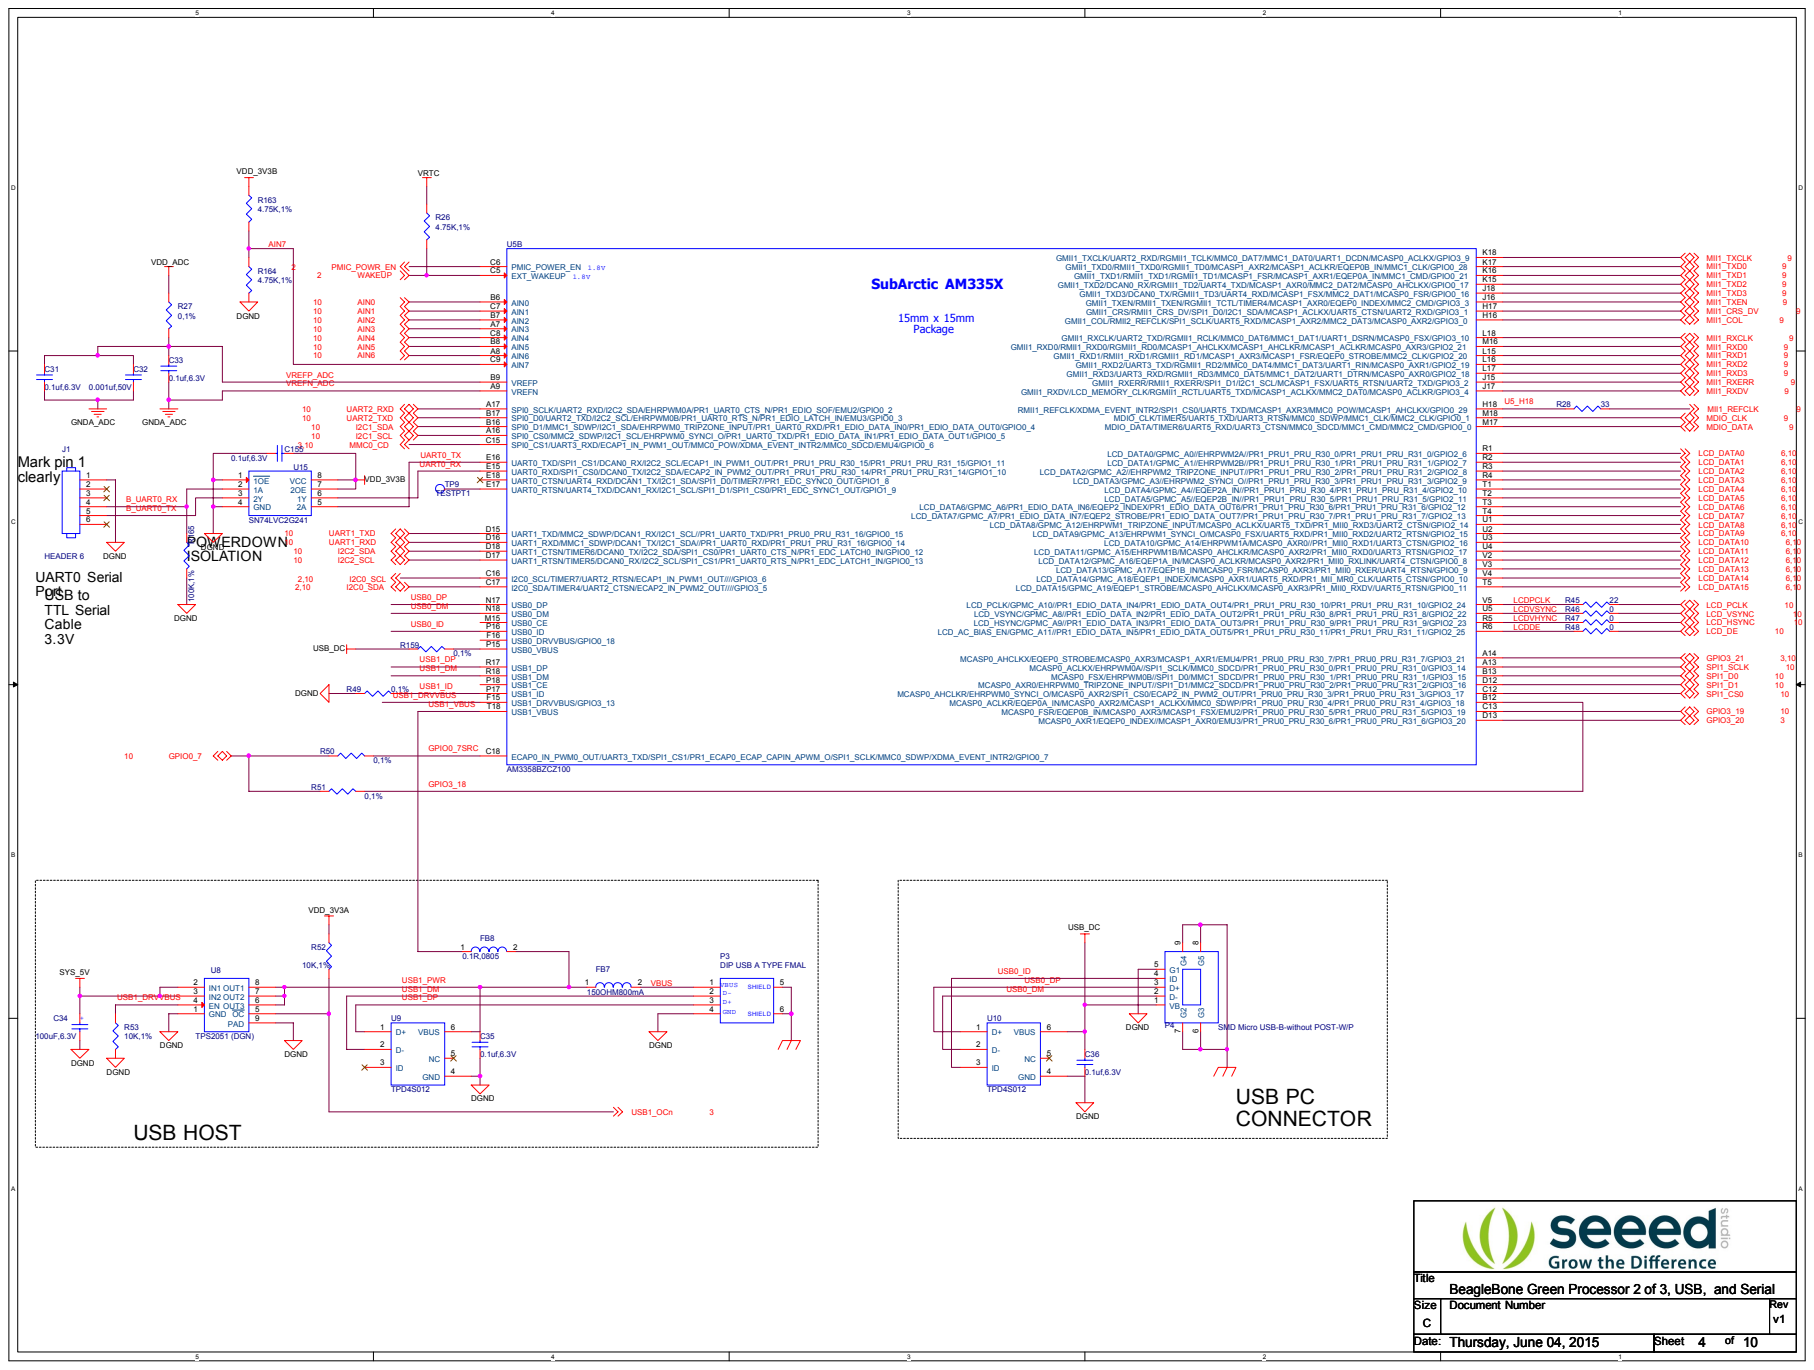
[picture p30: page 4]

DIP USB A TYPE FMAL

Title
BeagleBone Green Processor 2 of 3, USB, and Serial

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

Date: Date: Date: Thursday, June 04, 2015 Thursday, June 04, 2015 Thursday, June 04, 2015 | Sheet Sheet Sheet 4 4 4 of of of 10 10 10

# SubArctic AM335X

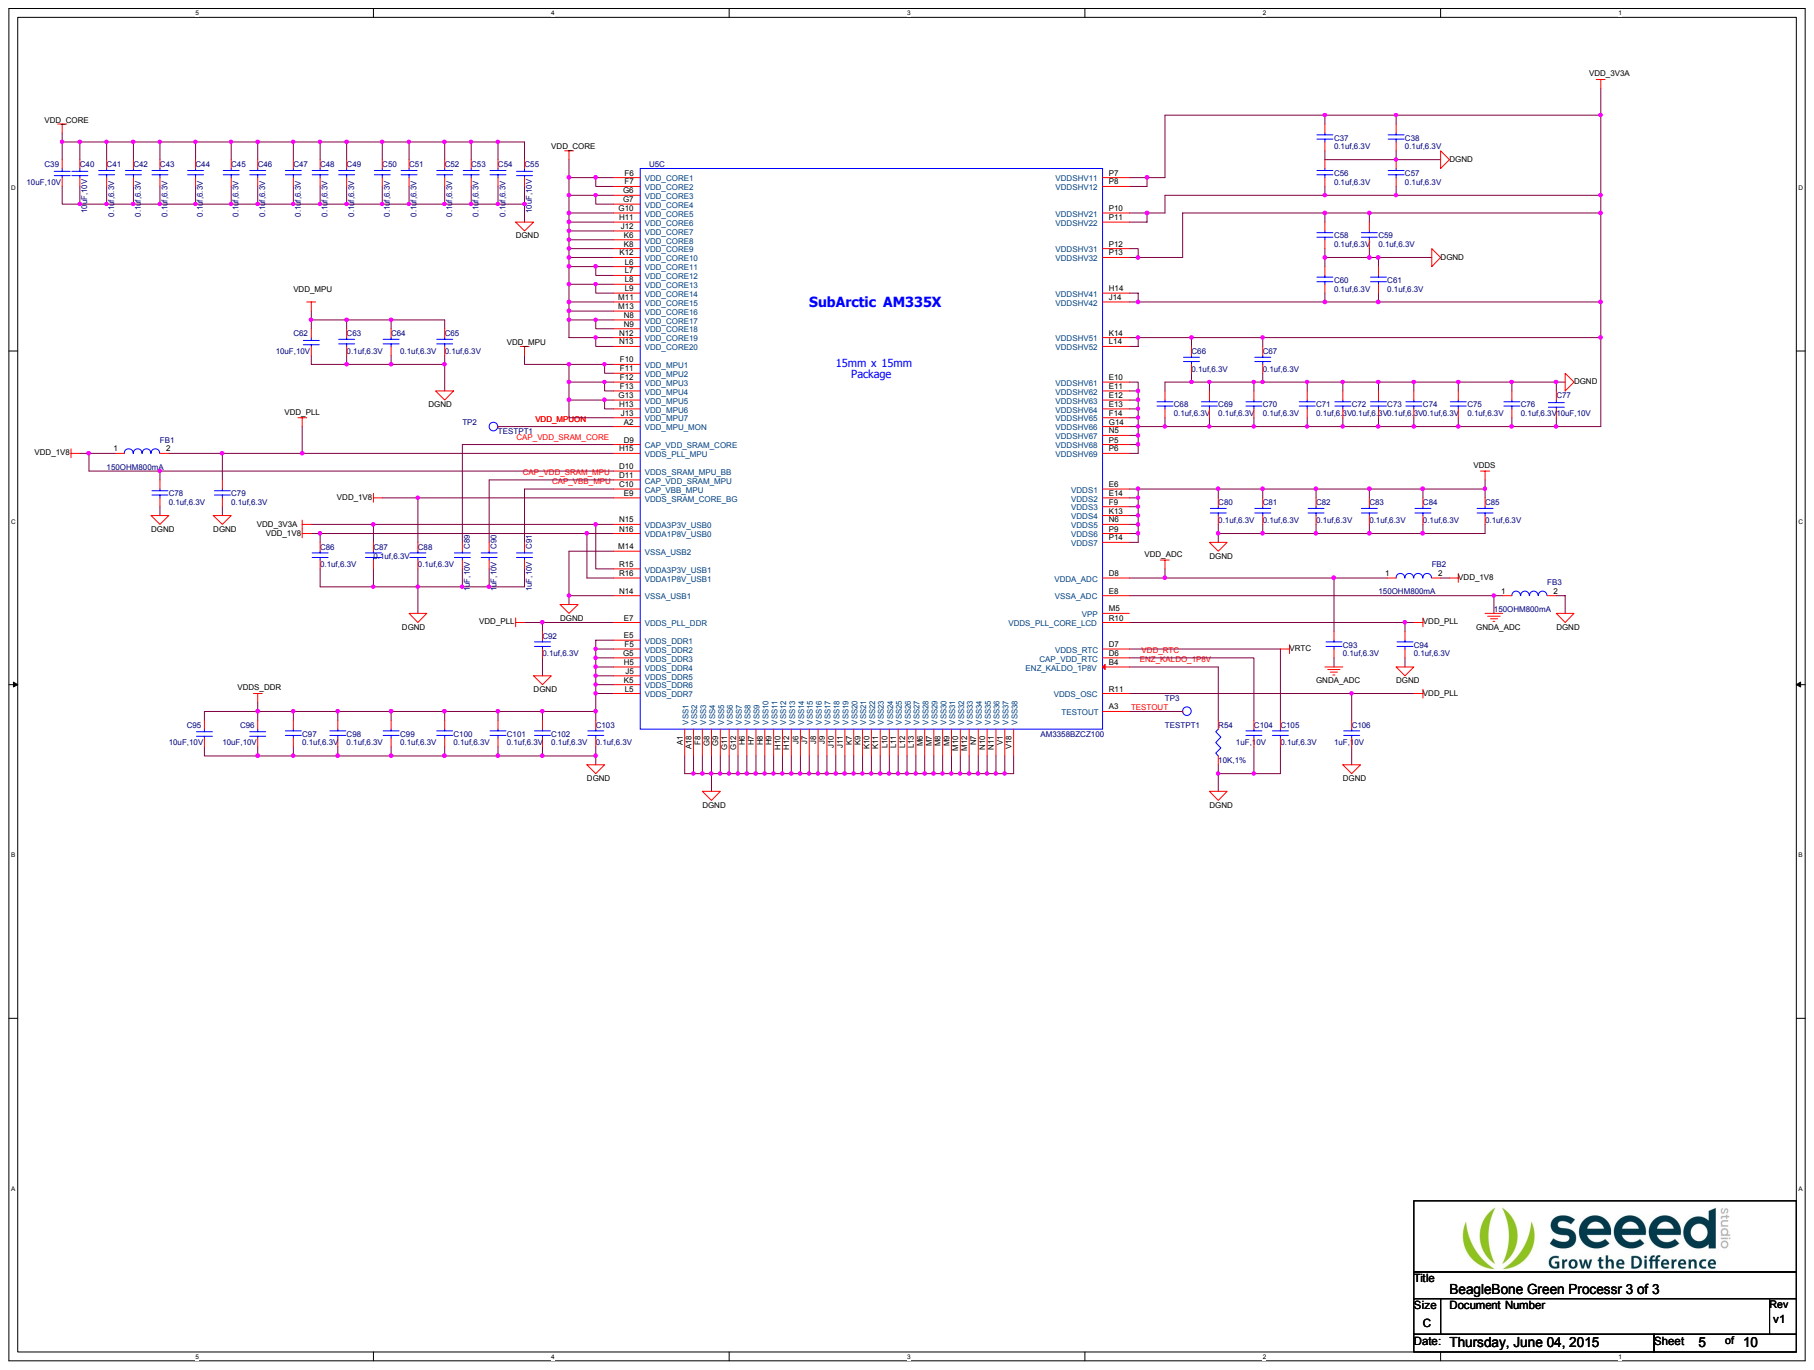
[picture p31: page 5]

Title
BeagleBone Green Processr 3 of 3

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

Date: Date: Date: Thursday, June 04, 2015 Thursday, June 04, 2015 Thursday, June 04, 2015 | Sheet Sheet Sheet 5 5 5 of of of 10 10 10

D | D

# User LED's

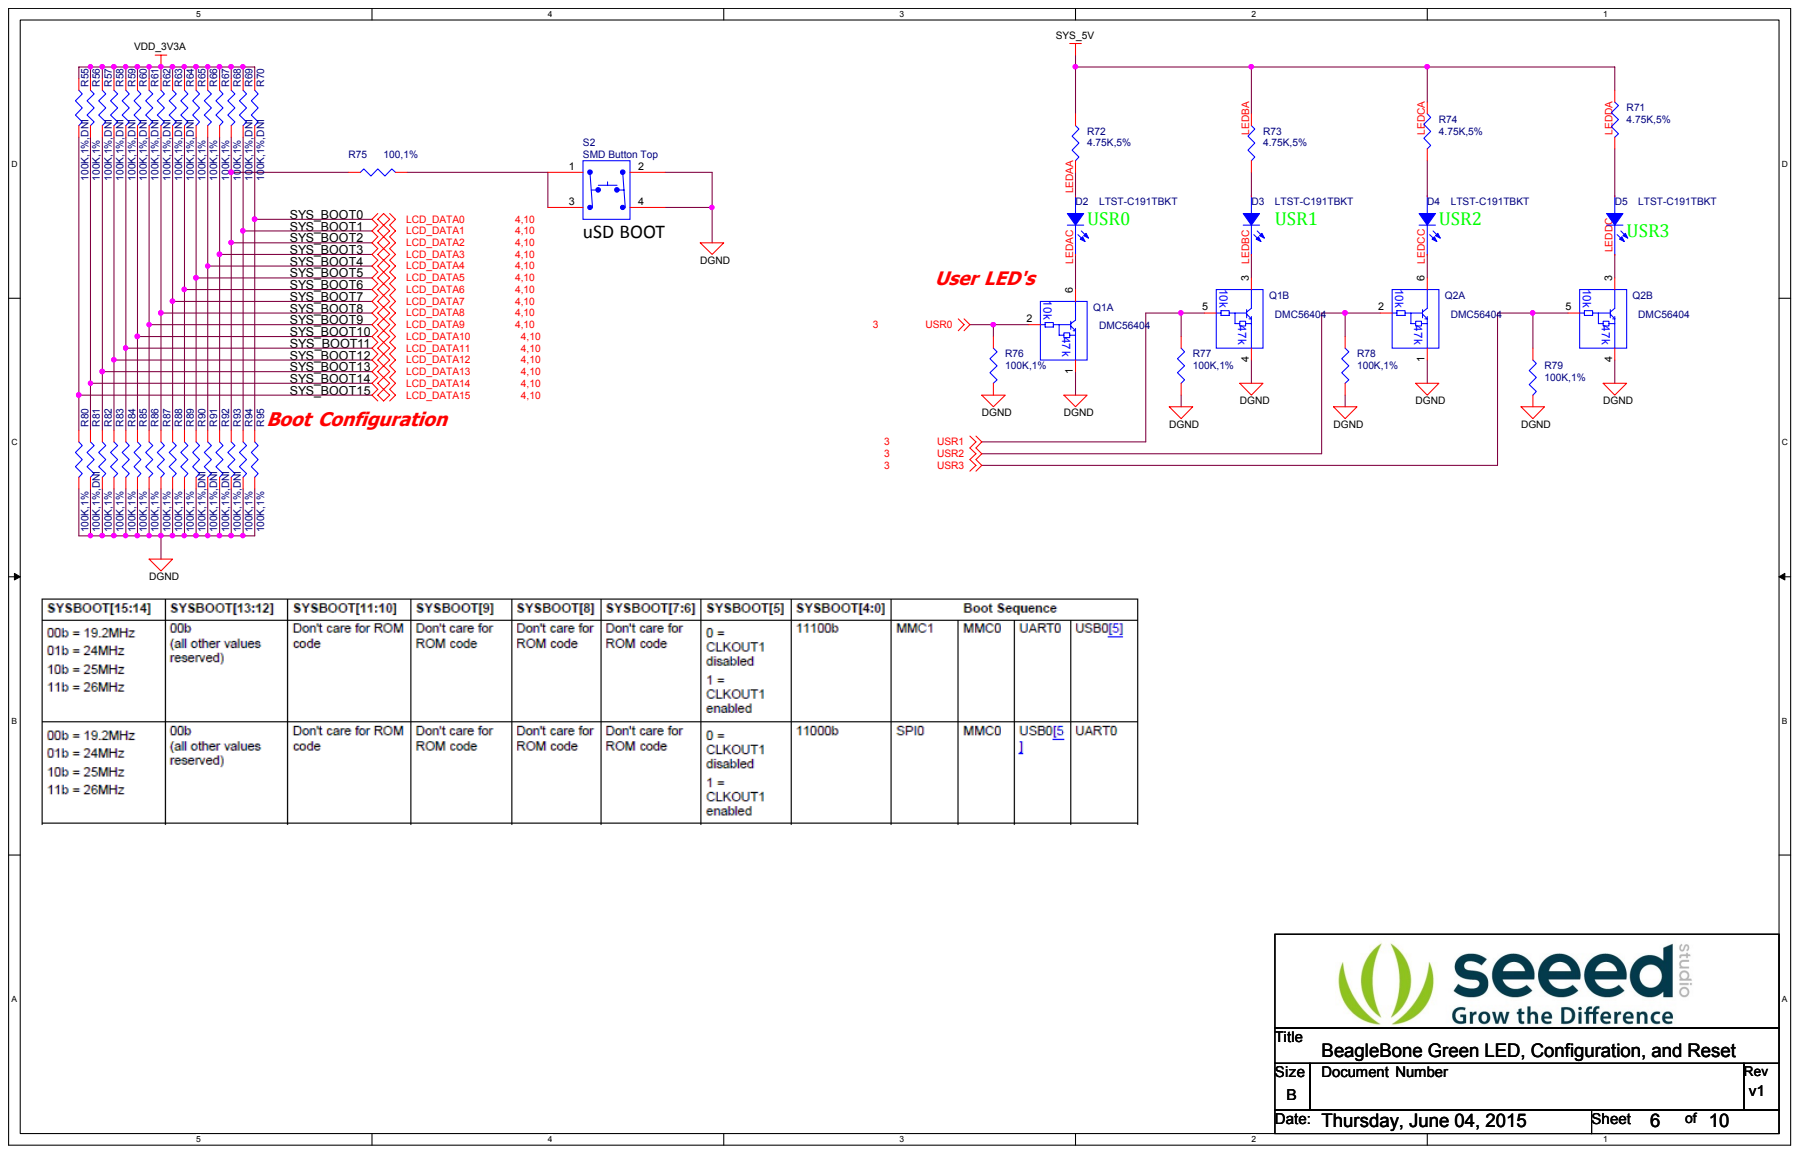
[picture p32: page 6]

SYS_BOOT3
SYS_BOOT4
SYS_BOOT5
SYS_BOOT6
SYS_BOOT7
SYS_BOOT8
SYS_BOOT9
SYS_BOOT10
SYS_BOOT11 SYS_BOOT12
SYS_BOOT13
SYS_BOOT14
SYS_BOOT15

Title
BeagleBone Green LED, Configuration, and Reset

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

Date: Date: Date: Thursday, June 04, 2015 Thursday, June 04, 2015 Thursday, June 04, 2015 | Sheet Sheet Sheet 6 6 6 of of of 10 10 10

D | D

# DDR3L SDRAM

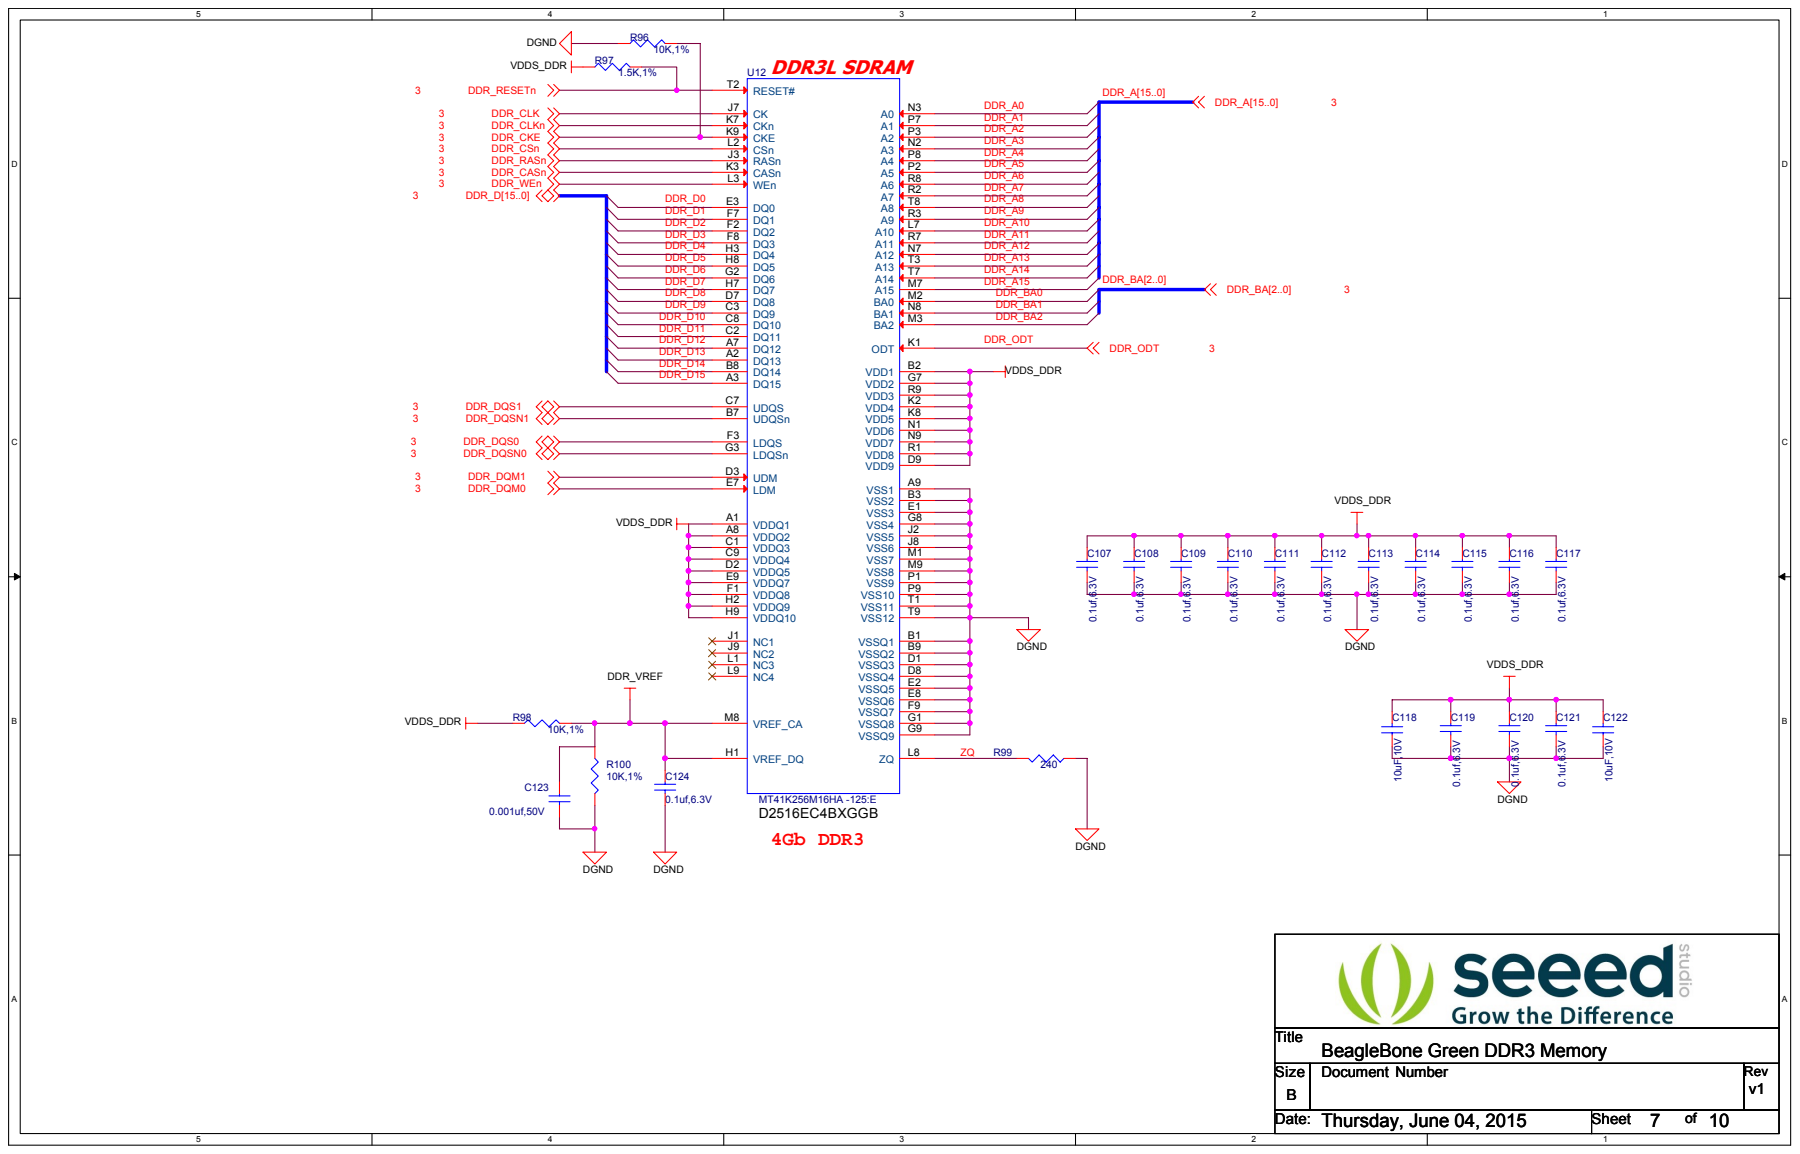
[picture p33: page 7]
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

Date: Date: Date: Thursday, June 04, 2015 Thursday, June 04, 2015 Thursday, June 04, 2015 | Sheet Sheet Sheet 7 7 7 of of of 10 10 10

D | D

## eMMC_VCCI

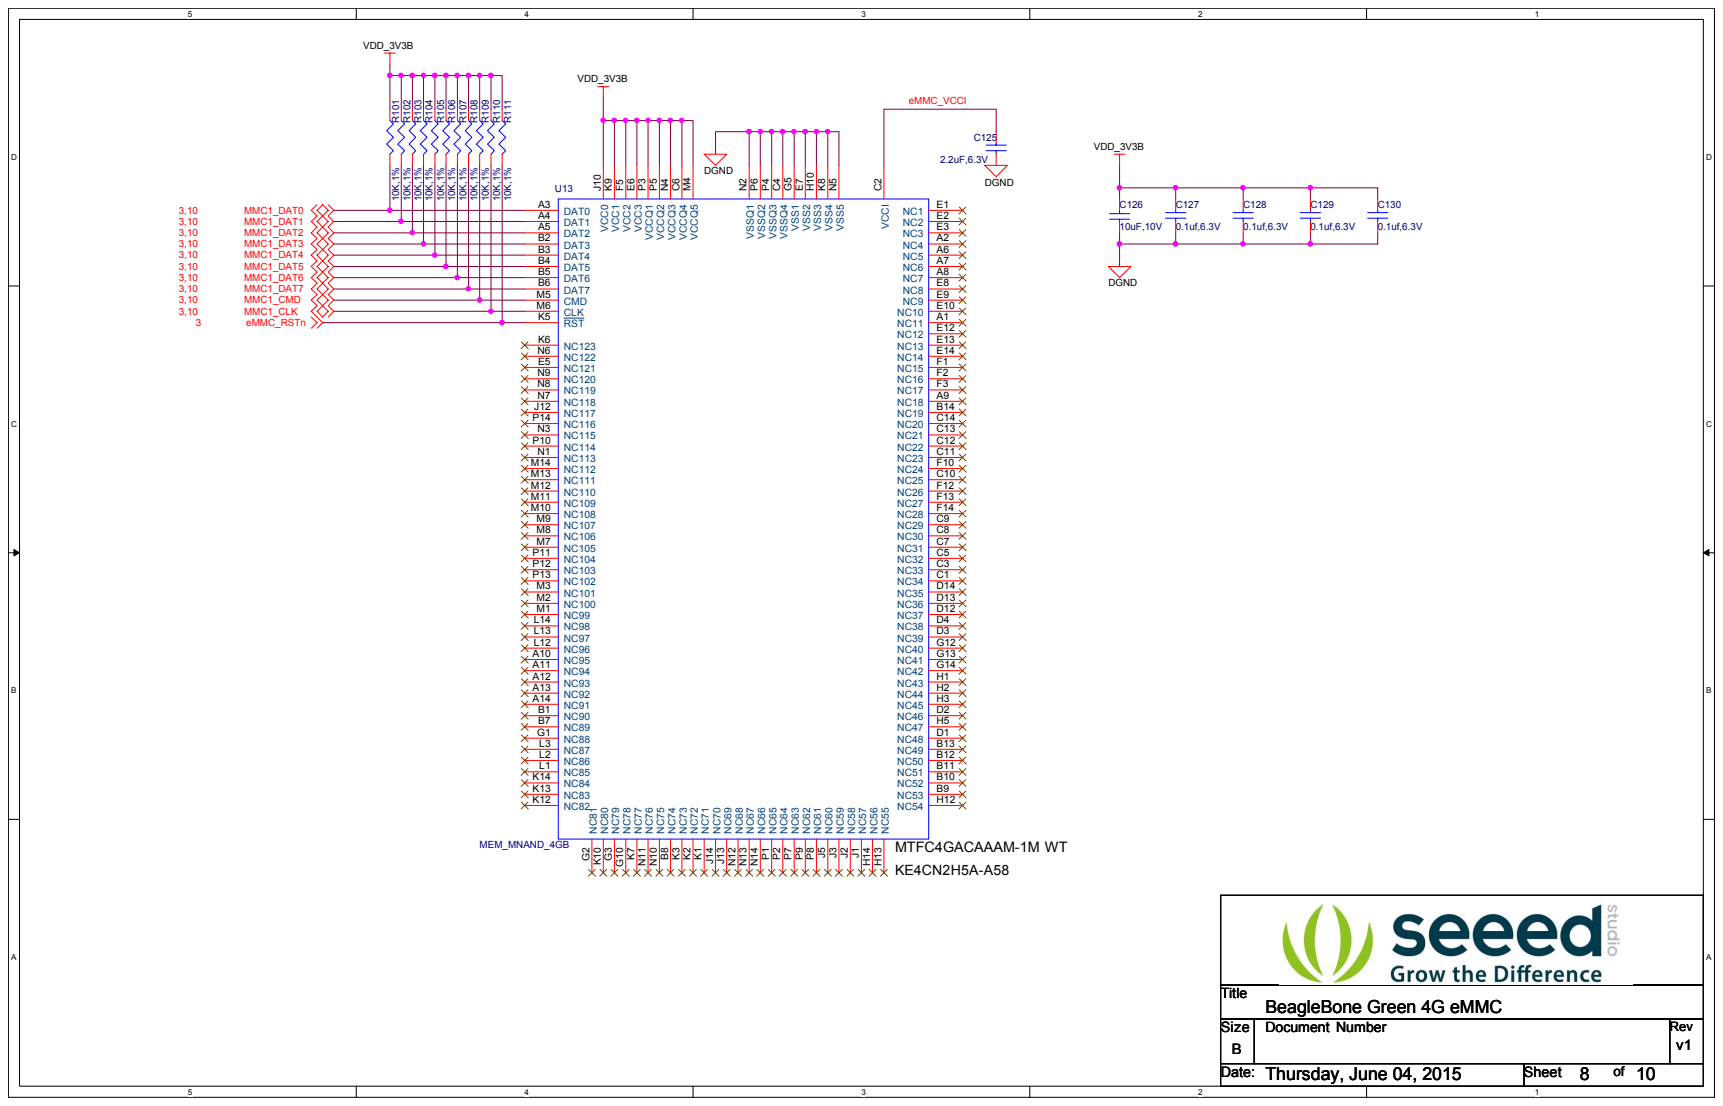
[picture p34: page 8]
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

Date: Date: Date: Thursday, June 04, 2015 Thursday, June 04, 2015 Thursday, June 04, 2015 | Sheet Sheet Sheet 8 8 8 of of of 10 10 10

D | D

## PHY_VDDCR

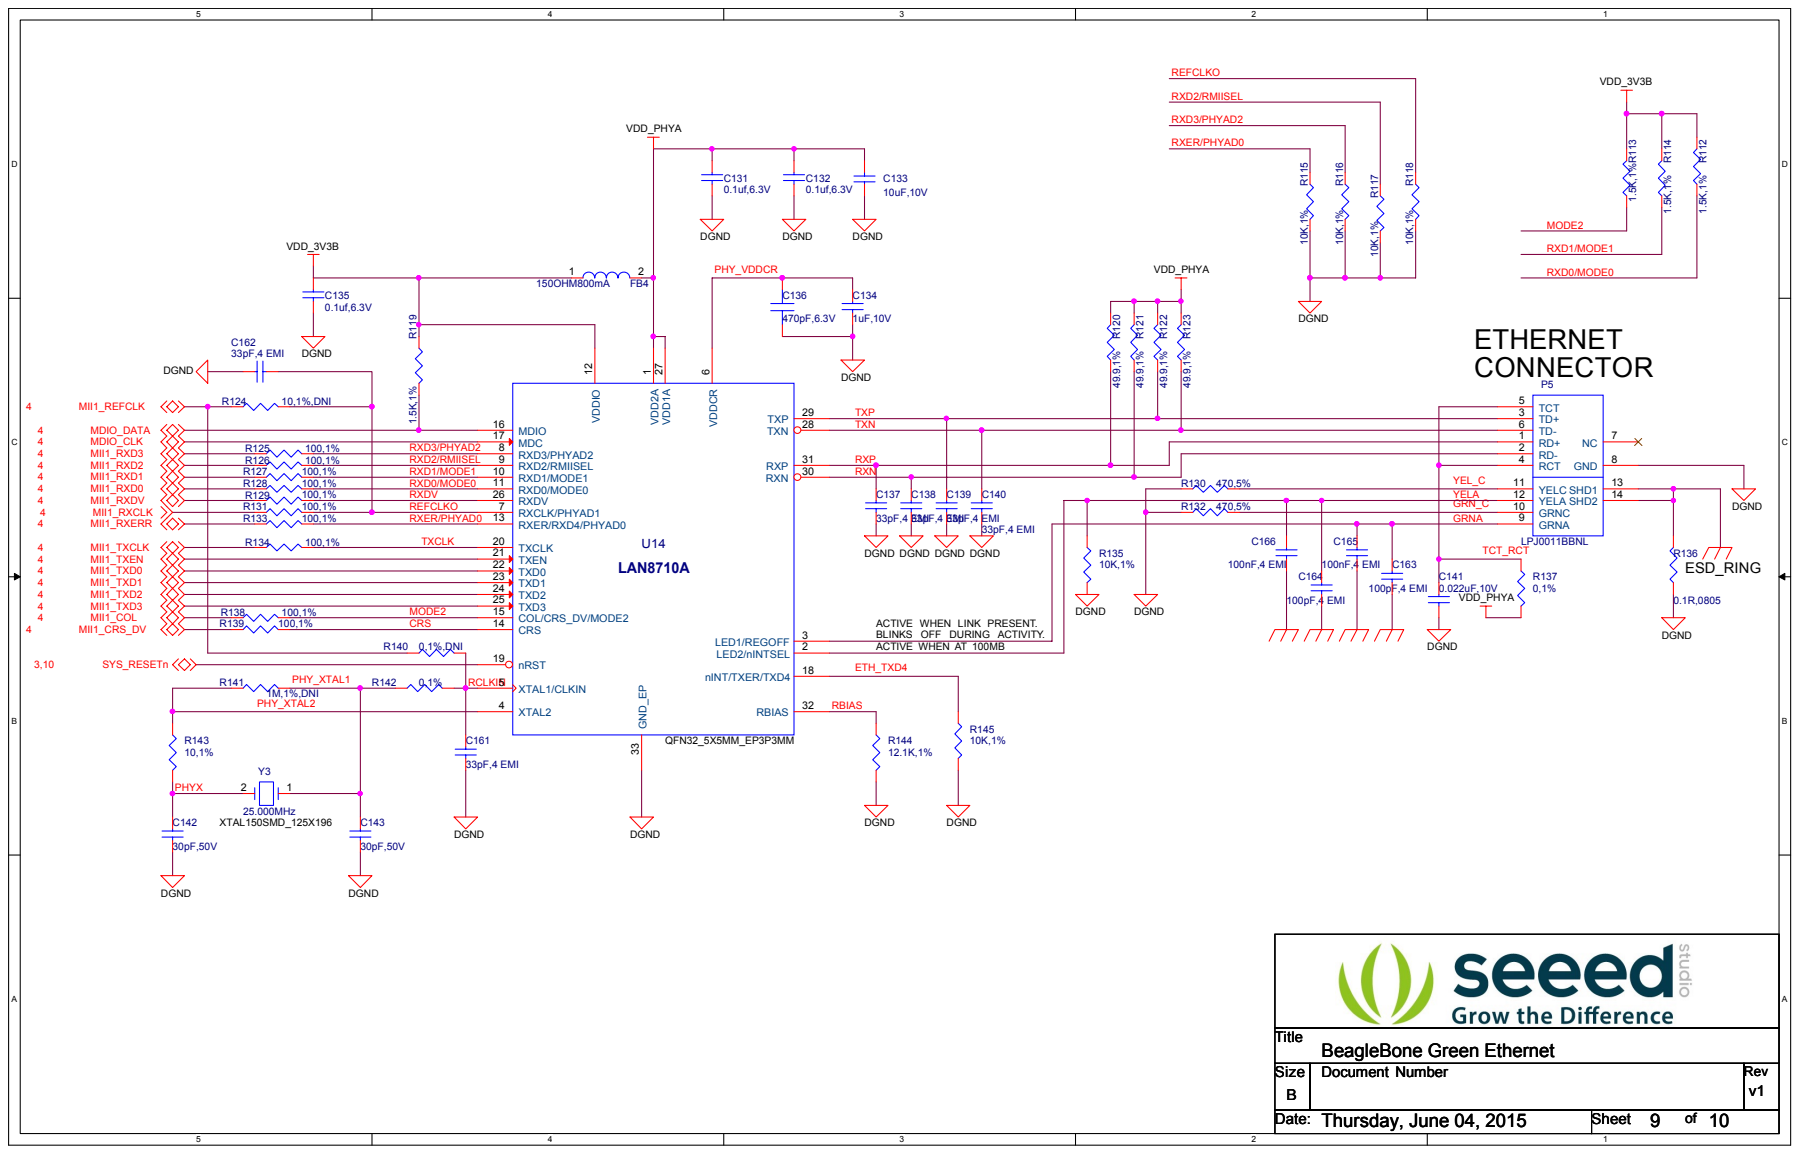
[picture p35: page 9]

DGND DGND

ACTIVE WHEN LINK PRESENT.
BLINKS OFF DURING ACTIVITY.
ACTIVE WHEN AT 100MB
ETH_TXD4

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

Date: Date: Date: Thursday, June 04, 2015 Thursday, June 04, 2015 Thursday, June 04, 2015 | Sheet Sheet Sheet 9 9 9 of of of 10 10 10

D | D
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
